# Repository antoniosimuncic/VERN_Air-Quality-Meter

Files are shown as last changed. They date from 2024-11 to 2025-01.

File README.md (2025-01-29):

# VERN' University  
Internet of Things Department  
Professor: doc. dr. sc. Petar Kolar, Roman Rubčić, dipl. ing. graf. teh.  
Student: Antonio Šimunčić  

**Smart air quality monitor**  

Zagreb, Croatia  
November, 2024  

# Introduction to the Smart Air Quality Monitor Project

Air pollution is becoming an increasingly serious environmental and health issue, affecting people's quality of life worldwide. Harmful particles and gases in the atmosphere can lead to numerous health problems, making air quality monitoring essential for protecting health and the environment.

The goal of this project is to develop a Smart Air Quality Monitor, a smart meteorological station that integrates advanced sensors to measure airborne dust particles, CO2, humidity, pressure, and temperature. This device would enable real-time air quality monitoring, providing users with critical information to help them make informed decisions and take necessary precautions.

# Week 1 - System architecture

Project Requirements:  

- **Temperature and Humidity Measurement**
- **Dust Particle Measurement** (PM1, PM2.5, PM4, PM10)
- **VOC Index Measurement** (Volatile Organic Compounds)
- **CO2 Level Measurement** in the Air
- **Atmospheric Pressure Measurement**
- **User Data Display**
- **Wireless Network Connectivity**

After defining the device requirements, I began searching for suitable components on platforms like Mouser, TME, and Aliexpress to find those that best match the specifications. The goal was to select reliable components that ensure high accuracy and longevity of the system, while also being compatible with the microcontroller and its software support.

For the microcontroller, I chose the ESP32-S3-WROOM-1 (N16R8) due to its affordable price, dual-core processor, ample onboard flash memory (16MB), and integrated PSRAM (8MB), which serves as a frame buffer for generating the graphical interface. Additionally, the microcontroller module includes built-in Wi-Fi and Bluetooth RF interfaces and an antenna, which significantly shortens development time and reduces the risk of wireless communication issues. 

**Block diagram:**  

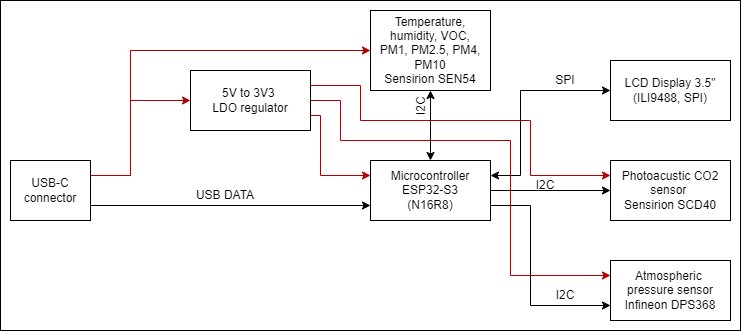
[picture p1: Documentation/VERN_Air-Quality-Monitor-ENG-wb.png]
Block diagram photo
  

# Week 2 - Schematic drawing

In week 2, I began creating the schematic in KiCad. The first task was to place all the selected components in the schematic, followed by a detailed study of the datasheets for the chosen components to ensure correct connections and desired system functionality. At this stage, I am also working on optimizing the schematic and the Bill of Materials (BOM) for a smooth transition to PCB design later on.

# Week 3 - Schematic release

In week 3, I completed the schematic design and released the finalized version. This involved thoroughly verifying all component connections and ensuring compatibility across the system, focusing on power distribution, signal integrity, and communication pathways between components. After careful checks, I created a preliminary Bill of Materials (BOM) and added detailed annotations to the schematic to guide the upcoming PCB layout phase. The release of the schematic marks a significant milestone, setting the foundation for the PCB design and allowing for initial testing.

**Schematic:** [Revision 10](https://github.com/antoniosimuncic/VERN_Air-Quality-Meter/blob/main/Hardware/100008_hw-vern-aqm/Schematic/100008_hw-vern-aqm.pdf)

# Week 4 - PCB design

In the fourth week of the project, I began designing the PCB based on the finalized schematic. This phase involved selecting the appropriate board dimensions, component placement, and routing the connections while considering design rules such as trace width, clearance, and power and heat management. A key focus was on USB differential pair impedance control, ensuring that the USB signal traces were routed with the correct 90Ω differential impedance to maintain signal integrity and reliable data transfer. I also worked on optimizing the layout for signal integrity, minimizing the length of high-speed signal traces, and ensuring proper reference planes and return paths for the components. After completing the layout and routing, I performed a Design Rule Check (DRC) to identify and correct any potential issues before moving on to generating the Gerber files for fabrication.

**PCB render:**  

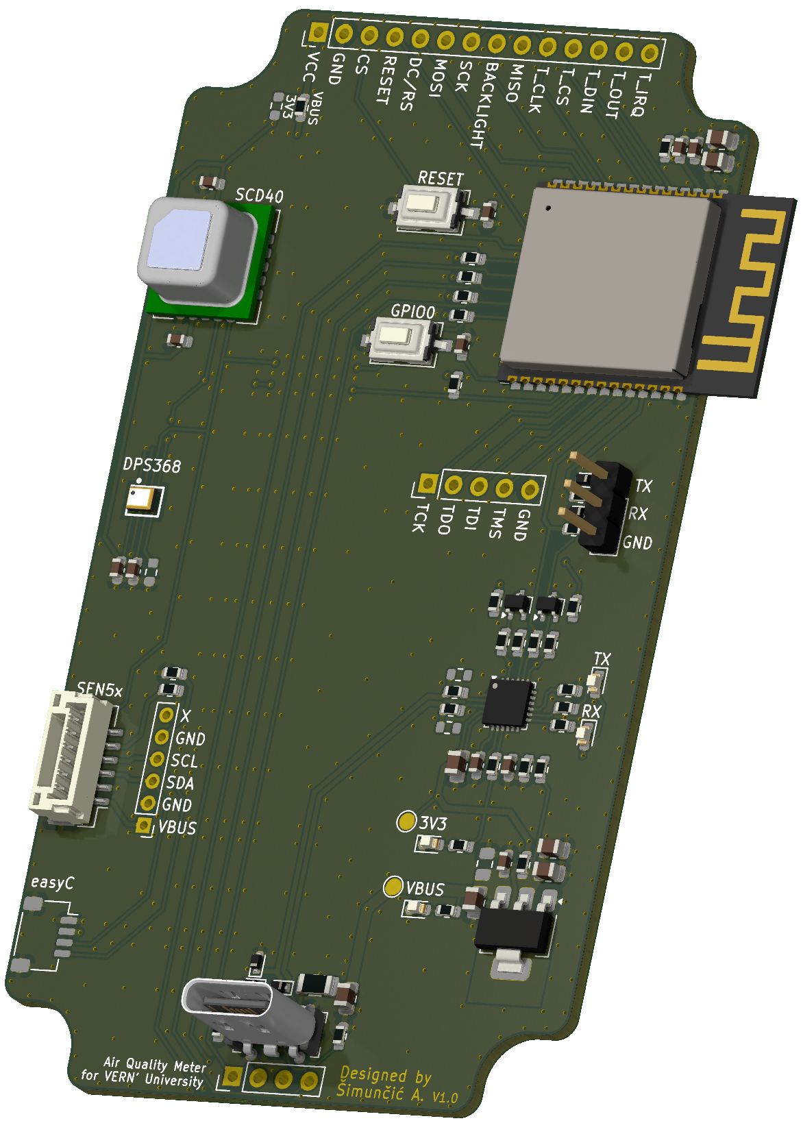
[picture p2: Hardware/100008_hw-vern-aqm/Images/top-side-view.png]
PCB render photo
  

# Week 5 - Component procurement  

In week 5, I focused on component procurement and ordering essential parts to prepare for assembly. I purchased components from Mouser to ensure the reliability of critical parts while sourcing additional items from Aliexpress for cost-effectiveness. Additionally, I ordered the PCBs and a stencil for solder application from JLCPCB. With components and PCBs on the way, the project is set to progress smoothly into the assembly phase once all parts arrive.

[Bill of Materials](https://html-preview.github.io/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)  

[Project expense report](https://github.com/antoniosimuncic/VERN_Air-Quality-Meter/blob/main/Documentation/project-expense-report.md)  

# Week 6 - PCB Assembly  

In week 6, I began assembling the PCB as the components and boards had arrived. Using the stencil from JLCPCB, I applied solder paste to the pads, and then I carefully placed each component onto the board, paying special attention to orientation and alignment. After assembling the board, I placed the board on an SMD hotplate reflow soldering station to perform the reflow soldering process. After the board cooled down, I inspected the connections to ensure the soldering process finished successfully. With the PCB assembly complete, I began the first board power-up to do the initial testing and troubleshooting.  

**Production process:**  

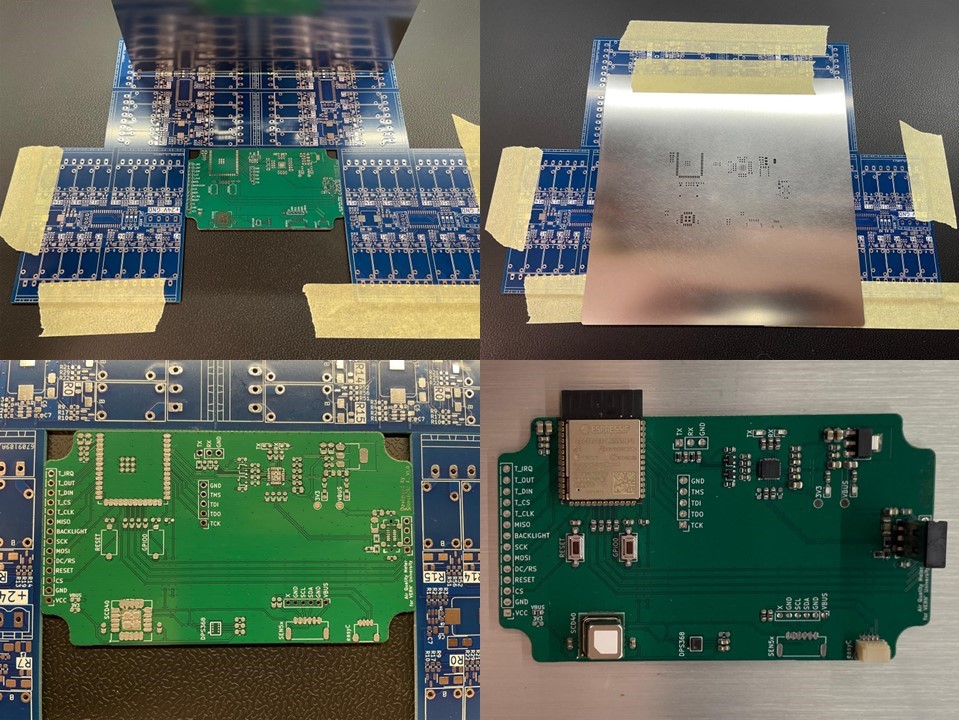
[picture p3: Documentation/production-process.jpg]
Photo of the production process
  

# Week 7 - Board Bring-Up  

In week 7, I focused on the initial bring-up of the PCB. After assembling the board, I verified the power rails and ensured all components received the correct voltages. Basic functionality, including communication interfaces such as UART and I2C, was tested to confirm proper connectivity between the microcontroller and peripherals. Rigol DS1054z oscilloscope was used to identify and resolve minor issues on the UART lines. Soldering fixes were necessary to ensure the board operated as expected. This stage established a solid foundation for further firmware development and system testing.  

**Sensor test source code:** [sensors-bring-up.cpp](https://github.com/antoniosimuncic/VERN_Air-Quality-Meter/blob/main/Documentation/sensors-bring-up.cpp)  

# Week 8 - Case design  

In week 8, I focused on designing a custom 3D-printed case for the device after I had confirmed the board functioned as expected. The design accounted for component placement, ventilation, and accessibility for ports and connectors. Aesthetics and durability were considered to ensure the case complemented the functionality and appearance of the project. This step helped prepare the device for practical use and testing in real-world conditions. The 3D print was made using PET-G on the BambuLab P1S printer.  

**Case design:**  

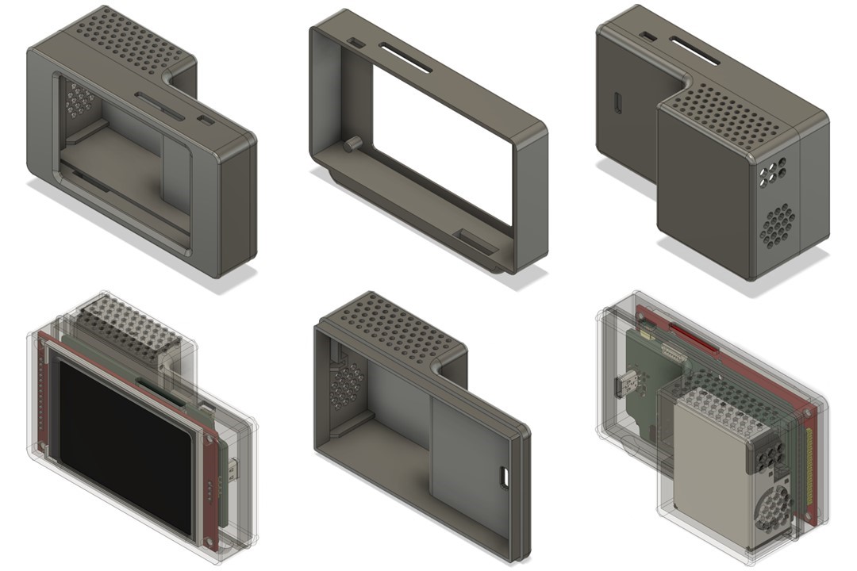
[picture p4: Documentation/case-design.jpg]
Photo of the case design
  

# Week 9: Firmware Architecture and Server Communication

In week 9, the focus was on developing and refining the firmware responsible for Wi-Fi connectivity, data acquisition, and communication with an HTTP server. Below is a detailed breakdown of the tasks completed and code implementations.

### Wi-Fi Connectivity

The firmware establishes a Wi-Fi connection using the ESP32-S3 microcontroller. A robust retry mechanism was implemented to handle connection failures.

**Code Snippet**:
```c
void connectToWifi() {
    uint8_t attempt = 0;
    while (attempt < WIFI_RETRIES) {
        Serial.printf("Attempt %u to connect to Wi-Fi...\n", attempt++);
        WiFi.mode(WIFI_STA);
        WiFi.begin(SECRET_SSID, SECRET_PASSWORD);
        unsigned long startAttemptTime = millis();
        while (WiFi.status() != WL_CONNECTED && millis() - startAttemptTime < WIFI_TIMEOUT) {
            delay(10);
            yield();
        }
        if (WiFi.status() == WL_CONNECTED) {
            Serial.println("Connected to Wi-Fi");
            Serial.print("IP Address: ");
            Serial.println(WiFi.localIP());
            return;
        }
        Serial.println("Failed to connect. Retrying...");
        delay(2000);
        attempt++;
    }
    Serial.println("Exceeded maximum retry attempts. Check your Wi-Fi credentials or network.");
}
```

### Server Communication

Data collected from sensors is sent to an HTTP server in JSON format. The sendDataToHTTPServer function handles this process, including constructing the JSON payload and managing HTTP requests.

**Request body:**
```json
{
 "mac_address": "AA:BB:CC:DD:EE:FF",
 "temperature": 22.5,
 "humidity": 45.0,
 "pm1": 10,
 "pm2_5": 20,
 "pm4": 25,
 "pm10": 30,
 "co2": 450,
 "voc": 100,
 "pressure": 1013.25
}
```
     
**Code Snippet:**
```c
void sendDataToHTTPServer(String mac_address, float temperature, float humidity, float pm1, float pm2_5, float pm4, float pm10, uint16_t co2, float voc, float pressure) {
    String jsonData = "{";
    jsonData += "\"mac_address\":\"" + mac_address + "\",";
    jsonData += "\"temperature\":" + String(temperature) + ",";
    jsonData += "\"humidity\":" + String(humidity) + ",";
    jsonData += "\"pm1\":" + String(pm1) + ",";
    jsonData += "\"pm2_5\":" + String(pm2_5) + ",";
    jsonData += "\"pm4\":" + String(pm4) + ",";
    jsonData += "\"pm10\":" + String(pm10) + ",";
    jsonData += "\"co2\":" + String(co2) + ",";
    jsonData += "\"voc\":" + String(voc) + ",";
    jsonData += "\"pressure\":" + String(pressure);
    jsonData += "}";

    if (WiFi.status() == WL_CONNECTED) {
        HTTPClient http;
        http.begin(SERVER_URL);
        http.addHeader("Content-Type", "application/json");
        int httpResponseCode = http.POST(jsonData);
        if (httpResponseCode > 0) {
            String response = http.getString();
            Serial.println("Response code: " + String(httpResponseCode));
            Serial.println("Response: " + response);
        } else {
            Serial.println("Error on sending POST: " + String(httpResponseCode));
        }
        http.end();
    } else {
        Serial.println("Wi-Fi not connected");
    }
}
```
**View Full Code:** [server_functions.cpp](https://github.com/antoniosimuncic/VERN_Air-Quality-Meter/blob/main/Software/100009-fw-vern-aqm/lib/server_functions/server_functions.cpp)

# Week 10: LCD Integration and Sensor Visualization

In week 10, the focus shifted to integrating the TFT display for visualizing sensor data. The firmware includes functionality for determining display colors based on sensor values, enhancing user experience.

### Dynamic Value Coloring

Each sensor value is displayed in a color-coded format to indicate its status (e.g., good, mediocre, bad, terrible).  
Functions like `getTempColor()` and `getHumidityColor()` determine the appropriate color for each value.

**Code Snippet:**
```c
uint16_t getHumidityColor(float humidity) {

    uint8_t targetHumidity = 50;
    if (abs(targetHumidity-humidity) <= 10) {
        return GOOD_COLOR;  // Green for humidity 40-60%
    } else if (abs(targetHumidity-humidity) <= 15) {
        return MEDIOCRE_COLOR;  // Yellow for humidity 35-65%
    } else if (abs(targetHumidity-humidity) <= 20) {
        return BAD_COLOR;  // Orange for humidity 30-70%
    } else {
        return TERRIBLE_COLOR;  // Red for humidity under 30 or over 70%
    }
}
```
**View Full Code:** [lcd_functions.cpp](https://github.com/antoniosimuncic/VERN_Air-Quality-Meter/blob/main/Software/100009-fw-vern-aqm/lib/lcd_functions/lcd_functions.cpp)

### Sensor Value Visualization

The display shows sensor values for temperature, humidity, CO2, VOC Index, and particulate matter (PM1, PM2.5, PM10). Each value is updated dynamically and rendered in real time.

**Code Snippet:**
```c
// Draw initial UI with Wi-Fi credentials
void drawUI() {
    sprite.fillSprite(BACKGROUND_COLOR);

    drawClockAndWiFi();

    sprite.setTextDatum(TL_DATUM); // Top-left
    sprite.setTextColor(TEXT_COLOR, TOP_BAR_COLOR);
    sprite.setTextSize(3);
    sprite.drawString("Time Zone", 10, 8);
    sprite.setTextDatum(TL_DATUM); // Top-left
    sprite.setTextColor(TEXT_COLOR, BACKGROUND_COLOR);
    sprite.setTextSize(3);
    sprite.drawString("SSID:", 20, 60);  sprite.drawString(SECRET_SSID, 120, 60);
    sprite.drawString("PASS:", 20, 120); sprite.drawString(SECRET_PASSWORD, 120, 120);
    sprite.drawString("IP:", 20, 180); sprite.drawString(ipString, 120, 180);

    sprite.pushSprite(0, 0);
    sprite.fillRect(0,35,480,285, BACKGROUND_COLOR);
    sprite.pushSprite(0, 0);

}

// Draw widgets with specified values
void drawWidget(int x, int y, int w, int h, const char* label, const char* unit, const char* value, uint16_t color) {
    // Draw the rounded rectangle
    sprite.fillRoundRect(x, y, w, h, 10, color);
    sprite.fillRoundRect(x + 5, y + 5, w - 10, h - 10, 5, BACKGROUND_COLOR);

    // Draw the label
    sprite.setTextColor(TEXT_COLOR, BACKGROUND_COLOR);
    sprite.setTextDatum(TC_DATUM);
    sprite.setTextSize(2);
    sprite.drawString(label, x + w / 2, y + 12);

    // Draw the value
    sprite.setTextSize(2);
    sprite.setTextColor(MEASUREMENT_TEXT_COLOR, BACKGROUND_COLOR);
    sprite.drawString(value, x + w / 2, (y + h / 2)-10);

    // Draw the measurement unit
    sprite.setTextColor(TEXT_COLOR, BACKGROUND_COLOR);
    sprite.setTextDatum(TC_DATUM);
    sprite.setTextSize(2);
    sprite.drawString(unit, x + w / 2, y + 80);
}

// Update each widget with new sensor values
void updateUI() {
    uint8_t x = 3;
    uint8_t y = 55;
    uint8_t w = 110;
    uint8_t h = 110;
    uint8_t v_space = 25;

    drawWidget(x +   0, y, w, h, "Temp",     "C",   String(TEMPERATURE, 1).c_str(),  getTempColor(TEMPERATURE));
    drawWidget(x + 120, y, w, h, "RH",       "%",   String(HUMIDITY, 1).c_str(),     getHumidityColor(HUMIDITY));
    drawWidget(x + 240, y, w, h, "CO2",      "ppm", String(CO2).c_str(),             getCO2Color(CO2));
    drawWidget(x + 360, y, w, h, "Pressure", "hPa", String(PRESSURE/100, 2).c_str(), getPressureColor(PRESSURE));

    drawWidget(x +   0, y + h + v_space, w, h, "VOC",   "Index", String(VOC_INDEX, 0).c_str(), getVOCColor(VOC_INDEX));
    drawWidget(x + 120, y + h + v_space, w, h, "PM1",   "ug/m3", String(PM1, 0).c_str(),       getPM1Color(PM1));
    drawWidget(x + 240, y + h + v_space, w, h, "PM2.5", "ug/m3", String(PM2_5, 0).c_str(),     getPM2_5Color(PM2_5));
    drawWidget(x + 360, y + h + v_space, w, h, "PM10",  "ug/m3", String(PM10, 0).c_str(),      getPM10Color(PM10));

    drawClockAndWiFi();

    sprite.pushSprite(0, 0);
}
```
### Time and Wi-Fi indicator  

The top bar of the display is reserved for a digital clock that syncs with a NTP time server on the Wi-Fi network, there is also a red/green dot in the upper right corner that shows Wi-Fi status.

```c
// Draw clock and Wi-Fi indicator
void drawClockAndWiFi() {
    // Draw clock
    unsigned long currentEpoch = timeClient.getEpochTime();
    String currentTime = epochToHoursMinutes(currentEpoch);

    sprite.fillRect(0,0,480,35, TOP_BAR_COLOR);
    sprite.setTextDatum(TC_DATUM); // Top-center
    sprite.setTextColor(TEXT_COLOR, TOP_BAR_COLOR);
    sprite.setTextSize(3);
    sprite.drawString(currentTime, 240, 8);

    // Draw WiFi symbol and indication
    if (WiFi.status() == WL_CONNECTED) {
        sprite.fillCircle(455, 18, 7, TFT_GREEN); // Indicate WiFi connection (green dot)
    } else {
        sprite.fillCircle(455, 18, 7, TFT_RED); // Indicate NO WiFi connection (red dot)
    }
}
```
**View Full Code:** [main.cpp](https://github.com/antoniosimuncic/VERN_Air-Quality-Meter/blob/main/Software/100009-fw-vern-aqm/src/main.cpp)

# Week 11 and 12: Node.js Server with visual data dashboard

Last part of the project was to design a web-application for managing the sensors and viewing and storing the data.  

**Web-App Repository**: [Nodejs-IoT-Server](https://github.com/antoniosimuncic/nodejs-iot-server)  

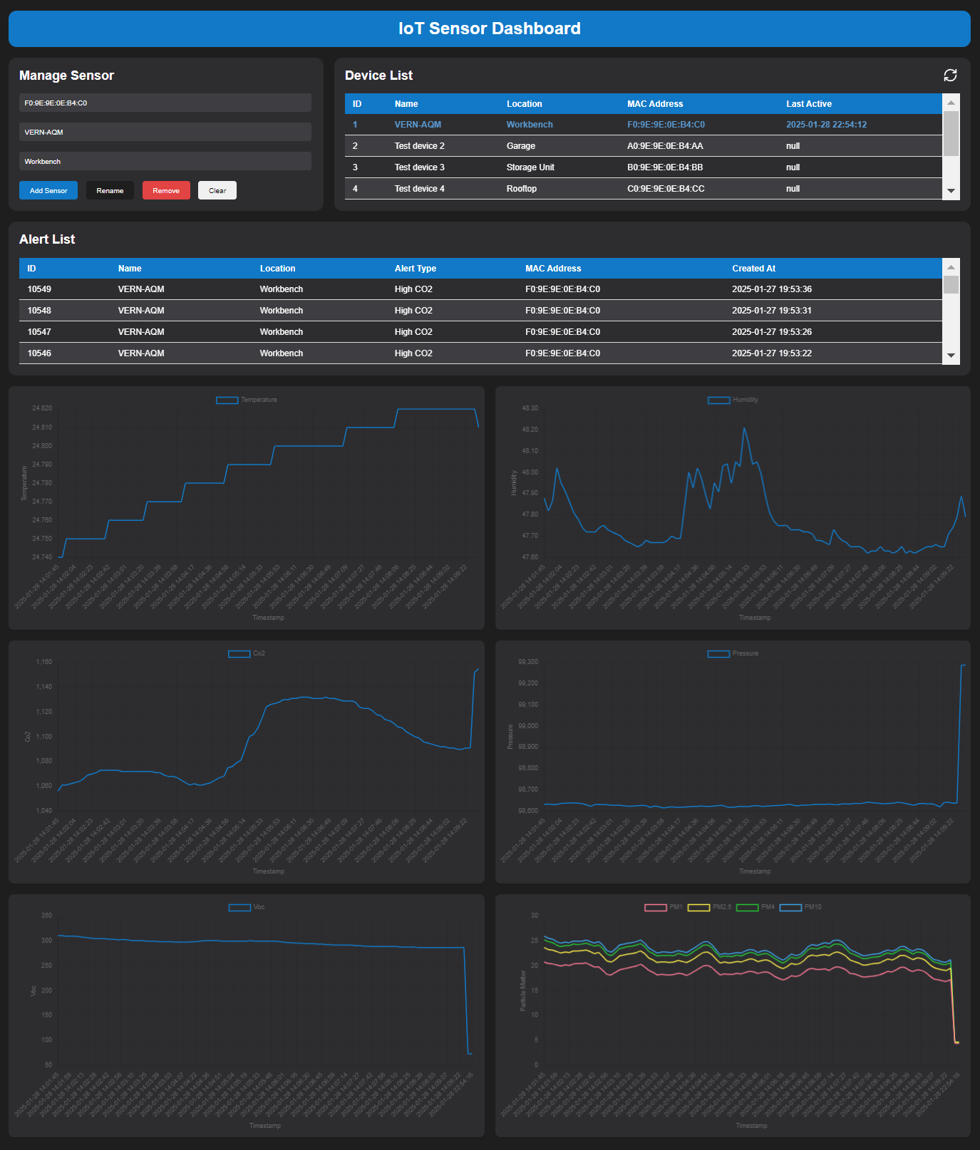
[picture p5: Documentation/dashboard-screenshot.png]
IoT Sensor Dashboard
  

---

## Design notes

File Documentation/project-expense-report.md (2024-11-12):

# Expense report:  
AliExpress: - 19.27€
- 2x 3.5" TFT LCD ILI9488 - 9.64€

JLCPCB: - 52.73€
- 5x 4-Layer PCB - 6.52€
- 1x SMD stencil - 6.62€
- Shipping - 29.04€
- Import duties and VAT - 10.55€

Mouser: - 77.11€
- Components - 61.69€
- VAT - 15.42€

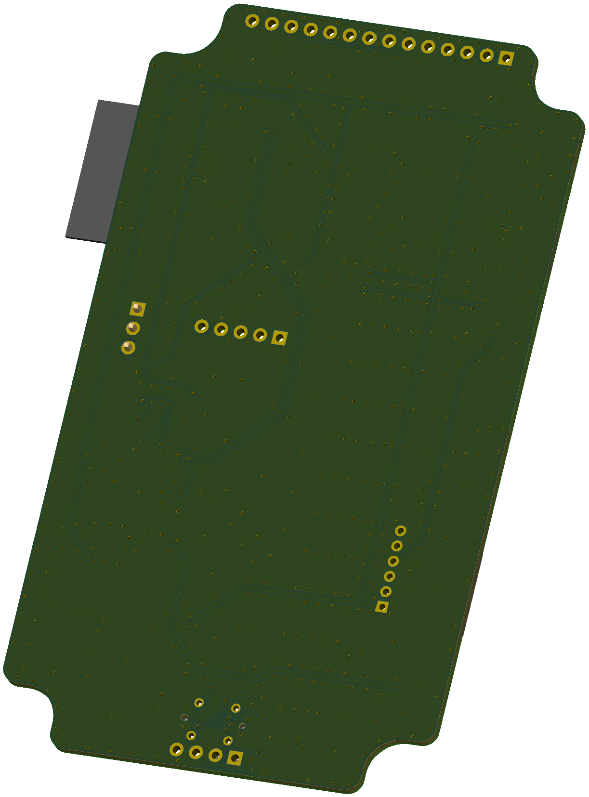
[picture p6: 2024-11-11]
Hardware/100008_hw-vern-aqm/Images/bottom-side-view.png

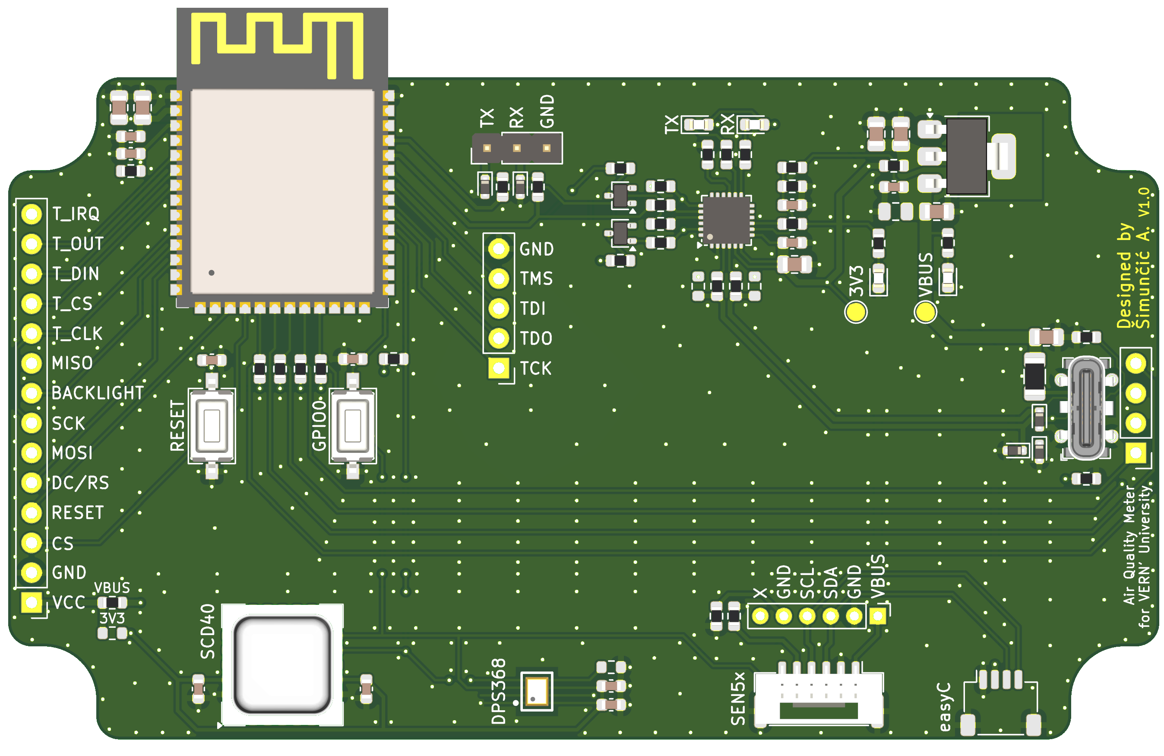
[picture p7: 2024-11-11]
Hardware/100008_hw-vern-aqm/Images/top-view.png

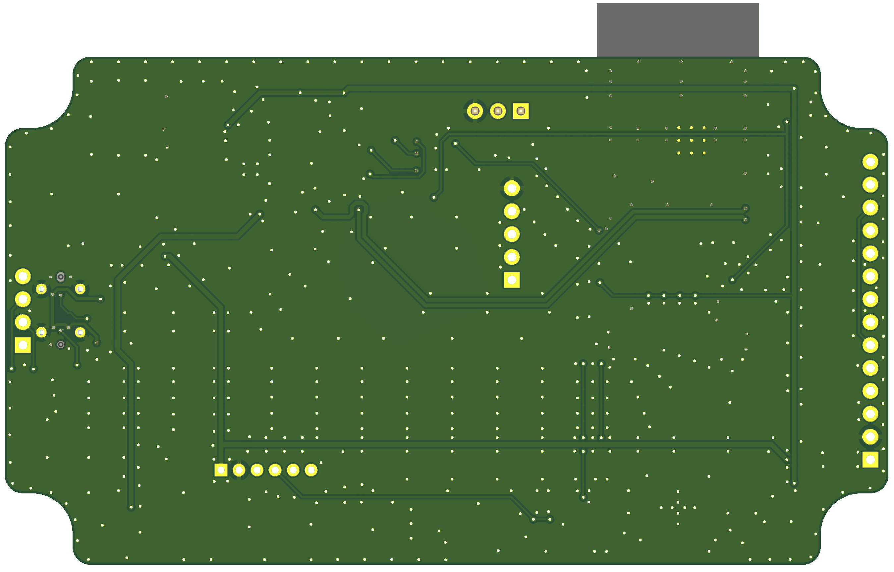
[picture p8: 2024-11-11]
Hardware/100008_hw-vern-aqm/Images/bottom-view.bmp

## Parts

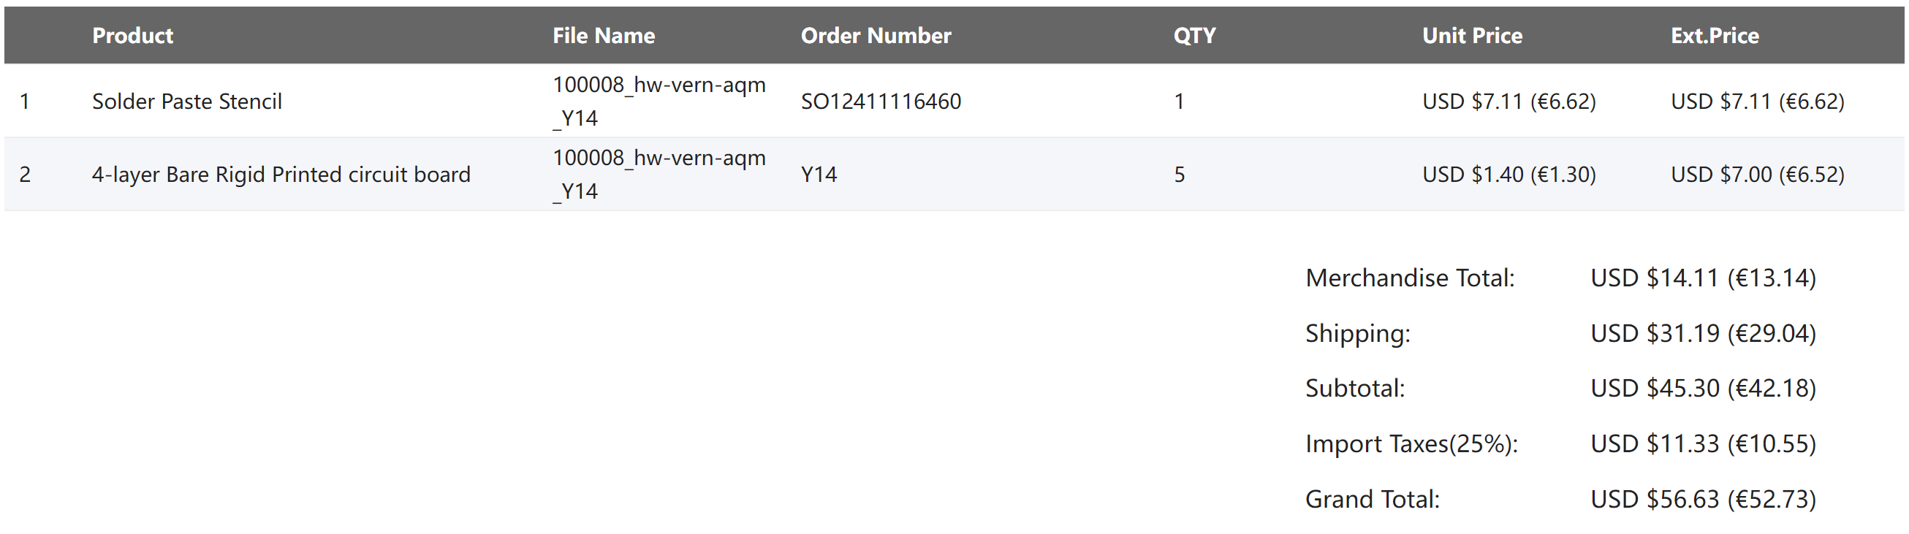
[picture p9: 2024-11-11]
Hardware/100008_hw-vern-aqm/Manufacturing/Procurement/jlcpcb-order.png

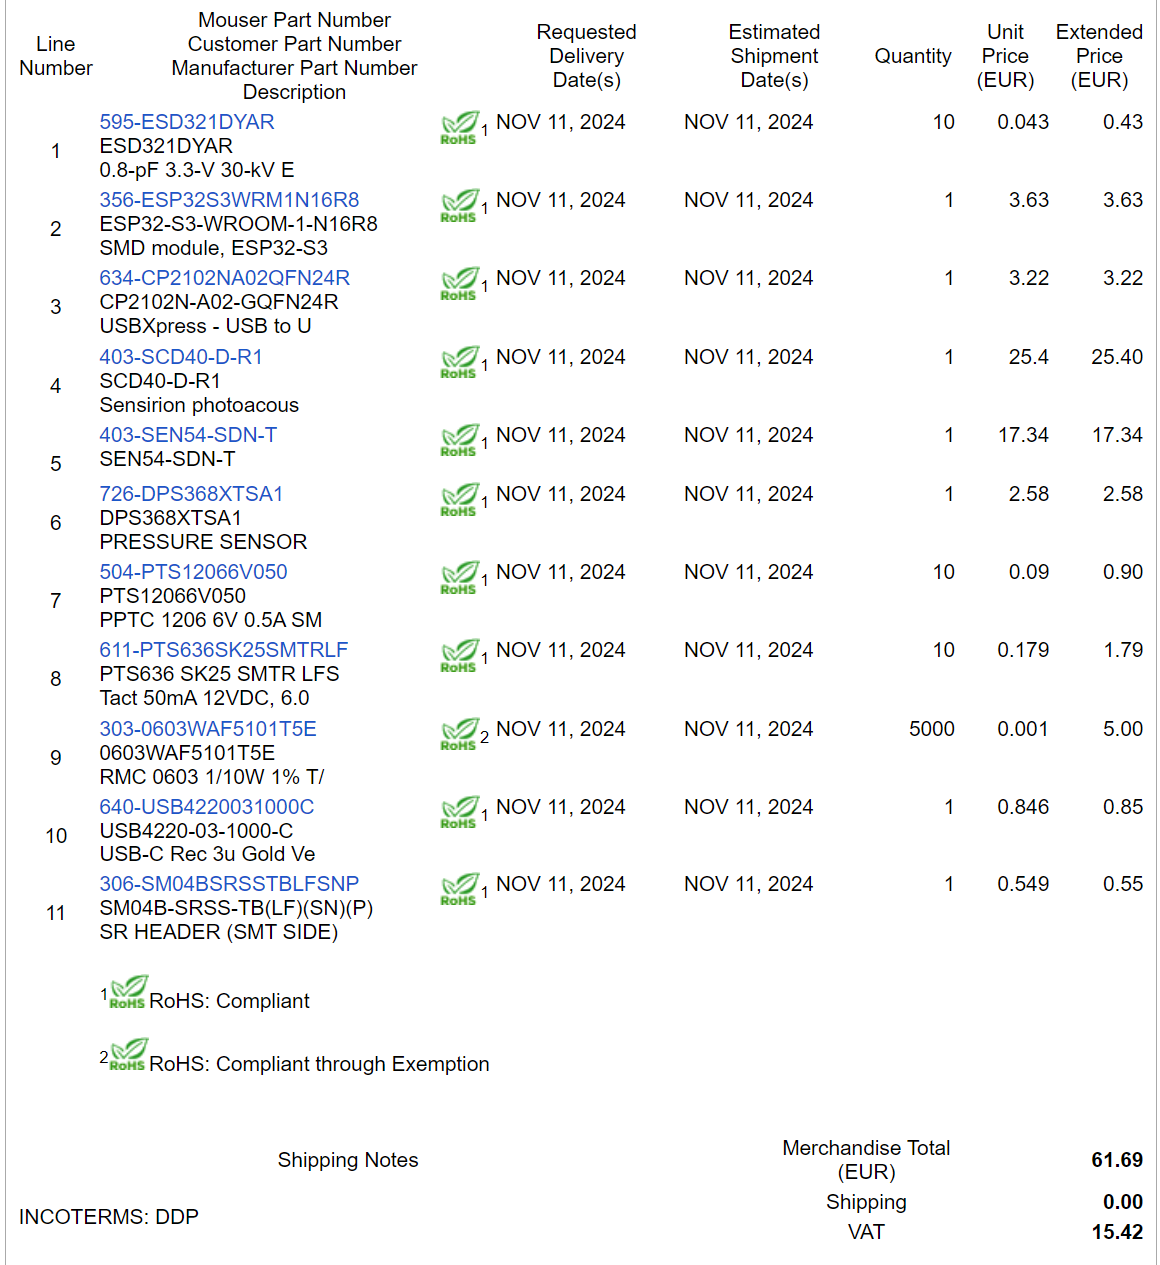
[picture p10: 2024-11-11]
Hardware/100008_hw-vern-aqm/Manufacturing/Procurement/mouser-order.png

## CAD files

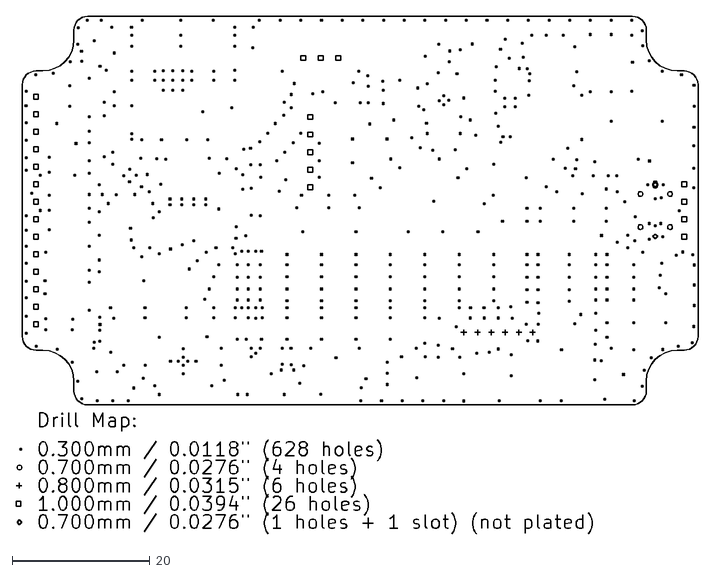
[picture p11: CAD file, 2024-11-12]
Hardware/100008_hw-vern-aqm/Manufacturing/Fabrication/Gerbers/100008_hw-vern-aqm-drl_map.dxf
98.9 x 75.0

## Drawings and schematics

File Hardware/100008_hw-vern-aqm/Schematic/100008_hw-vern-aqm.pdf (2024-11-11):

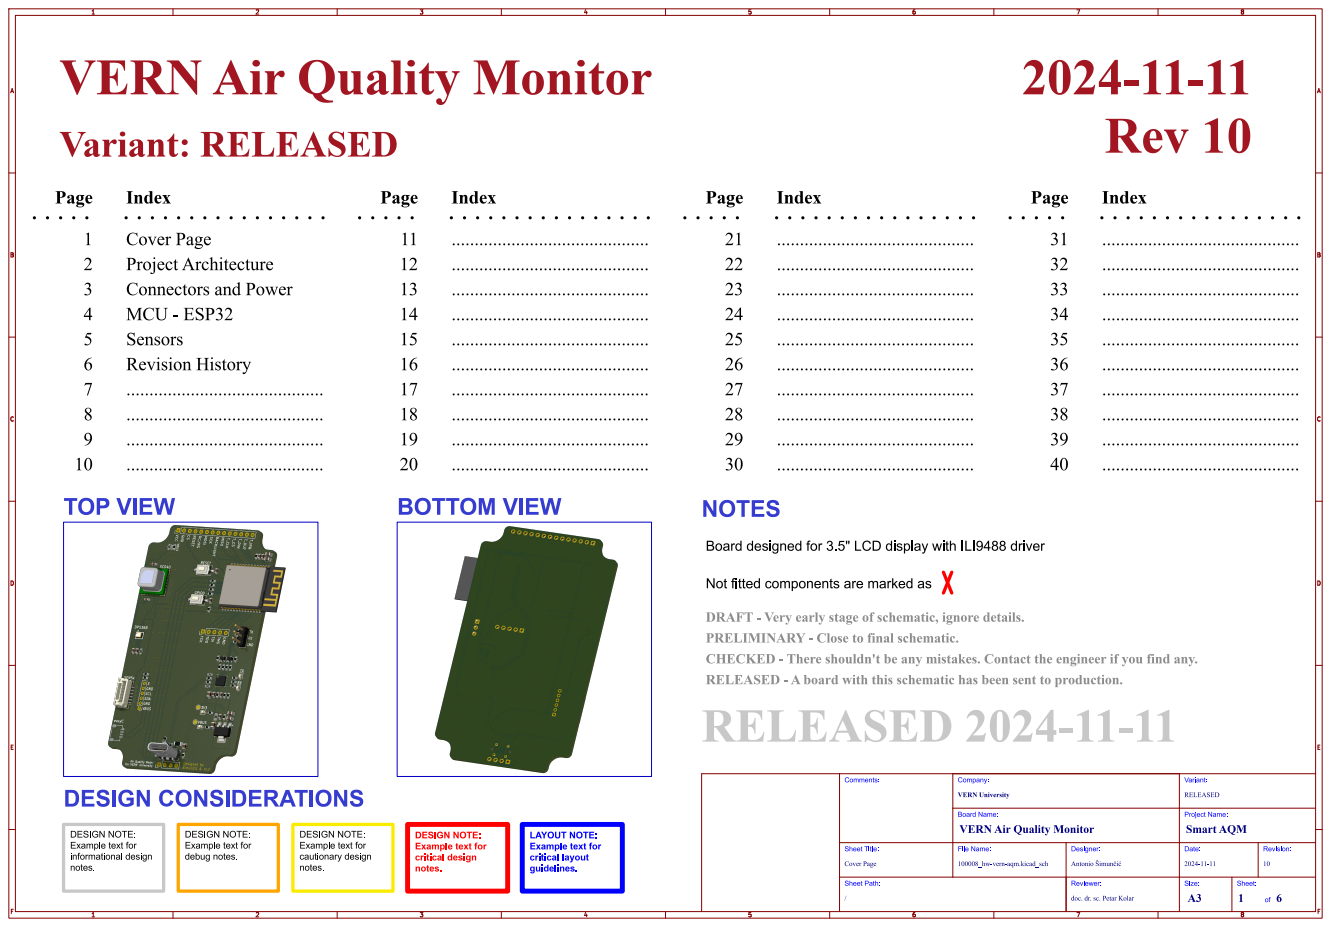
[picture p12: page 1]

Board designed for 3.5" LCD display with ILI9488 driver ...........................................

Not fitted components are marked as

DRAFT - Veryearlystageof schematic,ignoredetails.
PRELIMINARY - Closetofinal schematic.
CHECKED - Thereshouldn'tbeanymistakes.Contacttheengineerif youfindany.
RELEASED 2024-11-11

Revision: 10 Date: Project Name: 2024-11-11 Reviewer: doc.dr.sc.PetarKolar Designer:

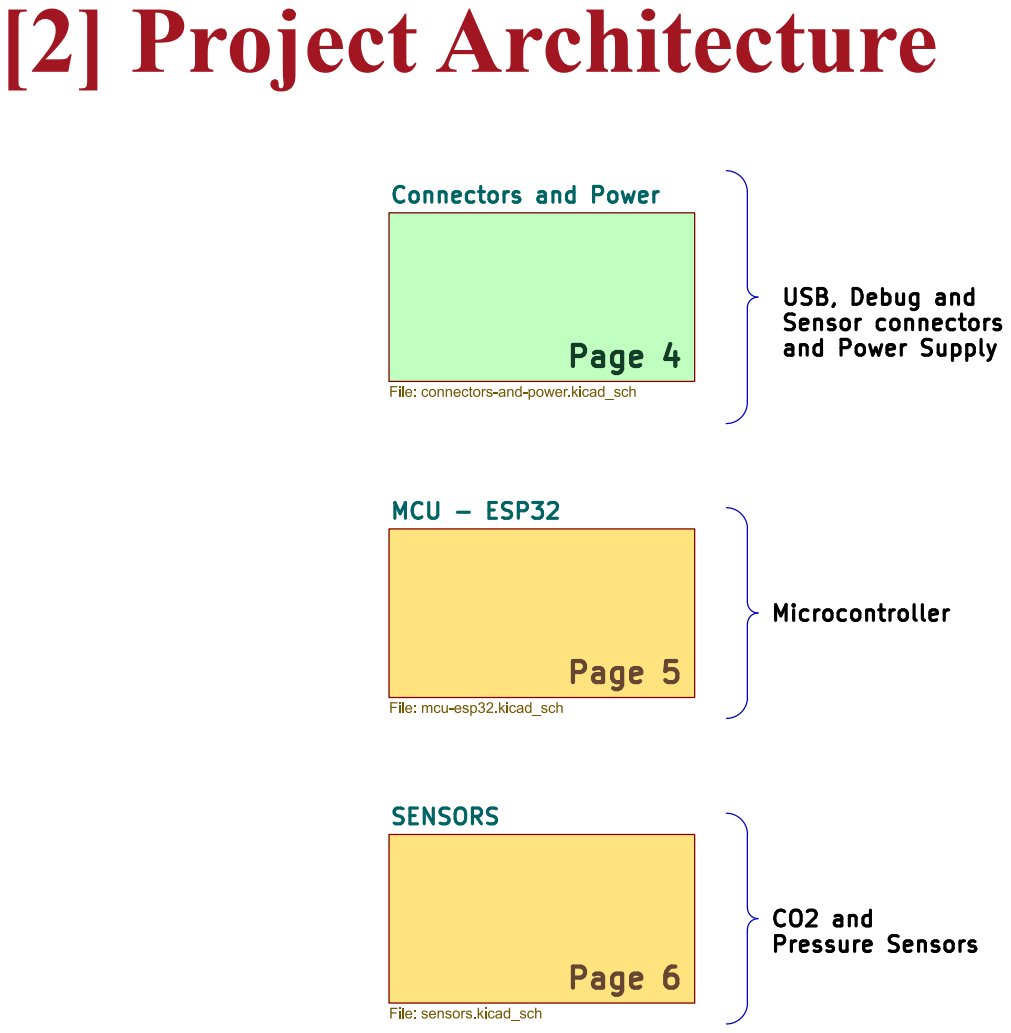
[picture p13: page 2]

/ProjectArchitecture/ Sheet Path: ProjectArchitecture Comments:

Revision: 10 Date: Project Name: LastModified Date Reviewer: doc.dr.sc.PetarKolar Designer:

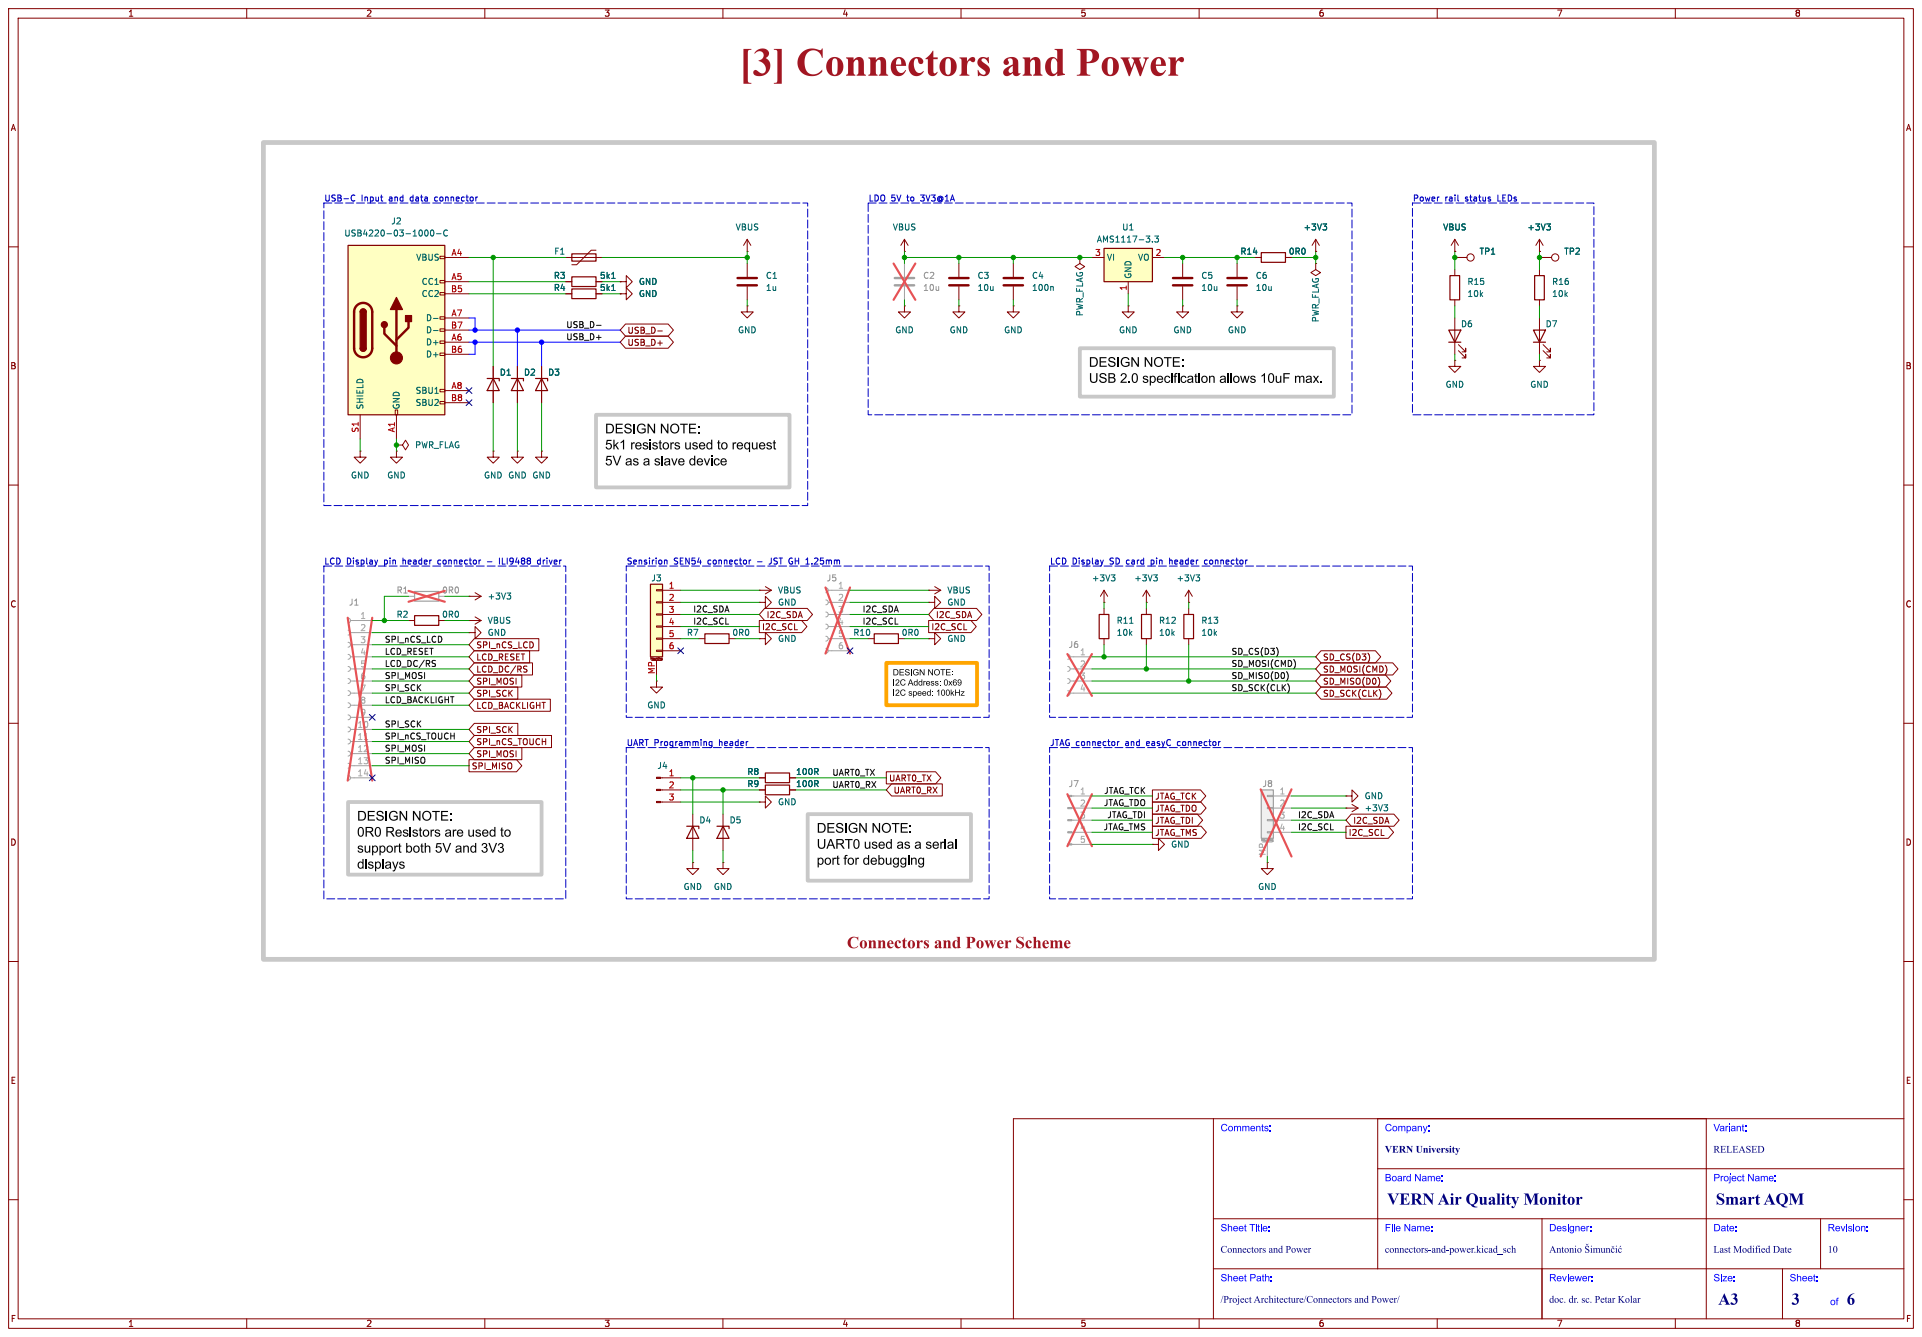
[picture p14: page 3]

USB 2.0 specification allows 10uF max. DESIGN NOTE:

5k1 resistors used to request
5V as a slave device
I2C_SDA UART0_RX

DESIGN NOTE:
0R0 Resistors are used to
support both 5V and 3V3
displays

/ProjectArchitecture/ConnectorsandPower/ Sheet Path: ConnectorsandPower Comments:

Revision: 10 Date: Project Name: LastModified Date Reviewer: doc.dr.sc.PetarKolar Designer:

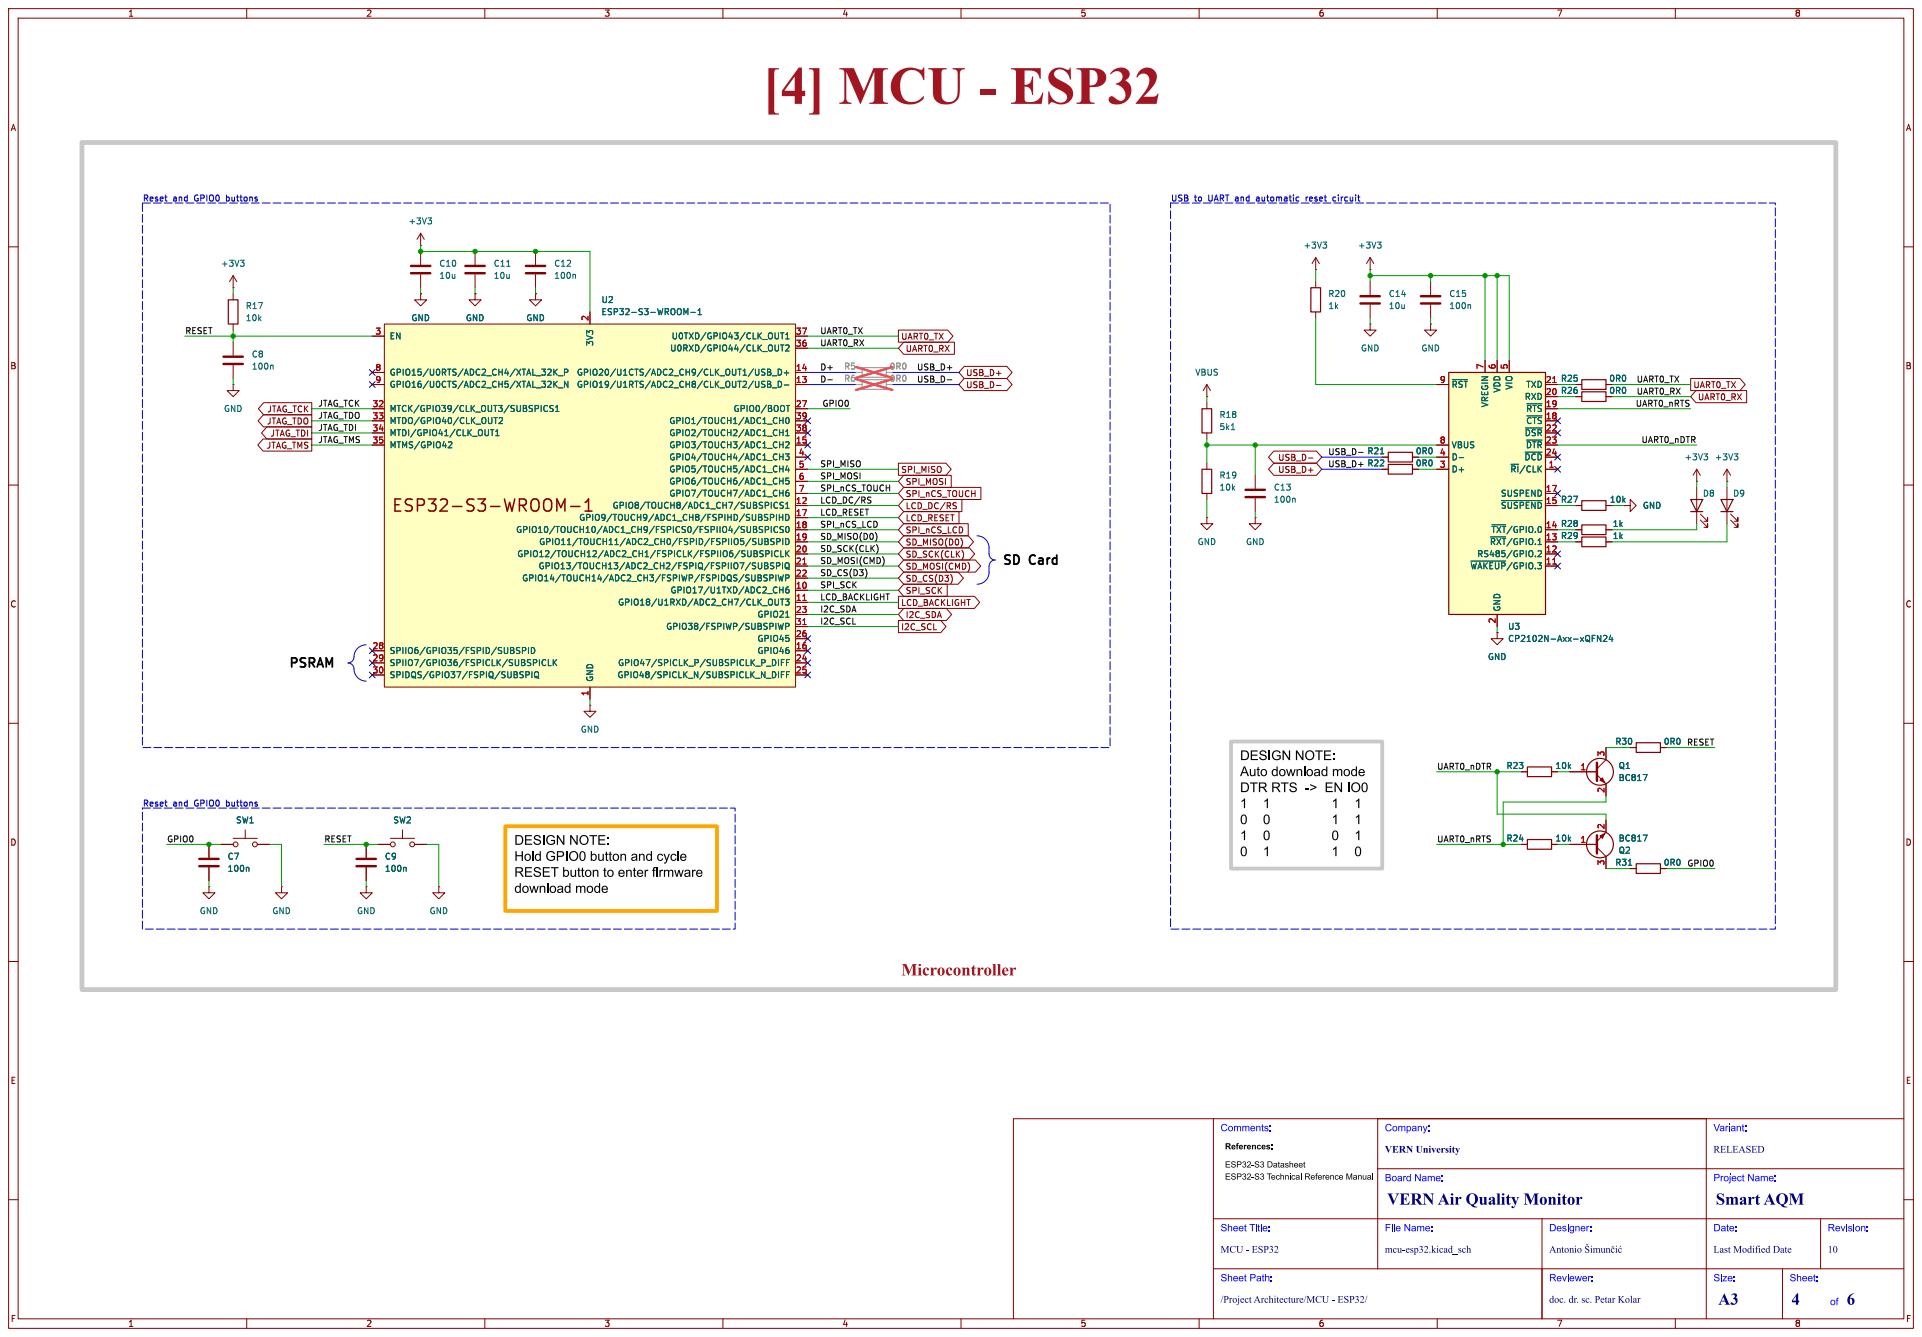
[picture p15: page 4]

2 GPIO12/TOUCH12/ADC2_CH1/FSPICLK/FSPIIO6/SUBSPICLK 20 GPIO13/TOUCH13/ADC2_CH2/FSPIQ/FSPIIO7/SUBSPIQ 21 GPIO14/TOUCH14/ADC2_CH3/FSPIWP/FSPIDQS/SUBSPIWP 22 GPIO21 23 GPIO47/SPICLK_P/SUBSPICLK_P_DIFF 24 GPIO48/SPICLK_N/SUBSPICLK_N_DIFF 25 GPIO45 26 GPIO0/BOOT 27 SPIIO6/GPIO35/FSPID/SUBSPID 28 SPIIO7/GPIO36/FSPICLK/SUBSPICLK 29 EN 3 SPIDQS/GPIO37/FSPIQ/SUBSPIQ 30 GPIO38/FSPIWP/SUBSPIWP 31 MTCK/GPIO39/CLK_OUT3/SUBSPICS1 32 MTDO/GPIO40/CLK_OUT2 33 MTDI/GPIO41/CLK_OUT1 34 MTMS/GPIO42 35 U0RXD/GPIO44/CLK_OUT2 36 U0TXD/GPIO43/CLK_OUT1 37 GPIO2/TOUCH2/ADC1_CH1 38 GPIO1/TOUCH1/ADC1_CH0 39 GPIO4/TOUCH4/ADC1_CH3 4 GPIO5/TOUCH5/ADC1_CH4 5 GPIO6/TOUCH6/ADC1_CH5 6 GPIO7/TOUCH7/ADC1_CH6 7 GPIO15/U0RTS/ADC2_CH4/XTAL_32K_P 8 GPIO16/U0CTS/ADC2_CH5/XTAL_32K_N 9 U2ESP32-S3-WROOM-1 R25 0R0 GND

2 GPIO12/TOUCH12/ADC2_CH1/FSPICLK/FSPIIO6/SUBSPICLK 20 GPIO13/TOUCH13/ADC2_CH2/FSPIQ/FSPIIO7/SUBSPIQ 21 GPIO14/TOUCH14/ADC2_CH3/FSPIWP/FSPIDQS/SUBSPIWP 22 GPIO21 23 GPIO47/SPICLK_P/SUBSPICLK_P_DIFF 24 GPIO48/SPICLK_N/SUBSPICLK_N_DIFF 25 GPIO45 26 GPIO0/BOOT 27 SPIIO6/GPIO35/FSPID/SUBSPID 28 SPIIO7/GPIO36/FSPICLK/SUBSPICLK 29 EN 3 SPIDQS/GPIO37/FSPIQ/SUBSPIQ 30 GPIO38/FSPIWP/SUBSPIWP 31 MTCK/GPIO39/CLK_OUT3/SUBSPICS1 32 MTDO/GPIO40/CLK_OUT2 33 MTDI/GPIO41/CLK_OUT1 34 MTMS/GPIO42 35 U0RXD/GPIO44/CLK_OUT2 36 U0TXD/GPIO43/CLK_OUT1 37 GPIO2/TOUCH2/ADC1_CH1 38 GPIO1/TOUCH1/ADC1_CH0 39 GPIO4/TOUCH4/ADC1_CH3 4 GPIO5/TOUCH5/ADC1_CH4 5 GPIO6/TOUCH6/ADC1_CH5 6 GPIO7/TOUCH7/ADC1_CH6 7 GPIO15/U0RTS/ADC2_CH4/XTAL_32K_P 8 GPIO16/U0CTS/ADC2_CH5/XTAL_32K_N 9 R6 0R0 R5 0R0 R26 0R0Q1 BC817

1 GPIO17/U1TXD/ADC2_CH6 10 GPIO18/U1RXD/ADC2_CH7/CLK_OUT3 11 GPIO8/TOUCH8/ADC1_CH7/SUBSPICS1 12 GPIO19/U1RTS/ADC2_CH8/CLK_OUT2/USB_D- 13 GPIO20/U1CTS/ADC2_CH9/CLK_OUT1/USB_D+ 14 GPIO3/TOUCH3/ADC1_CH2 15 GPIO46 16 GPIO9/TOUCH9/ADC1_CH8/FSPIHD/SUBSPIHD 17 GPIO10/TOUCH10/ADC1_CH9/FSPICS0/FSPIIO4/SUBSPICS0 18 GPIO11/TOUCH11/ADC2_CH0/FSPID/FSPIIO5/SUBSPID 19 3V3

2 RXD 20 TXD 21 ~{DSR} 22 ~{DTR} 23 ~{DCD} 24 D+ 3 D- 4 VIO

DESIGN NOTE:
Hold GPIO0 button and cycle
RESET button to enter firmware
download mode

/ProjectArchitecture/MCU- ESP32/ Sheet Path: MCU - ESP32 Comments: GND

Revision: 10 Date: Project Name: LastModified Date Reviewer: doc.dr.sc.PetarKolar Designer:

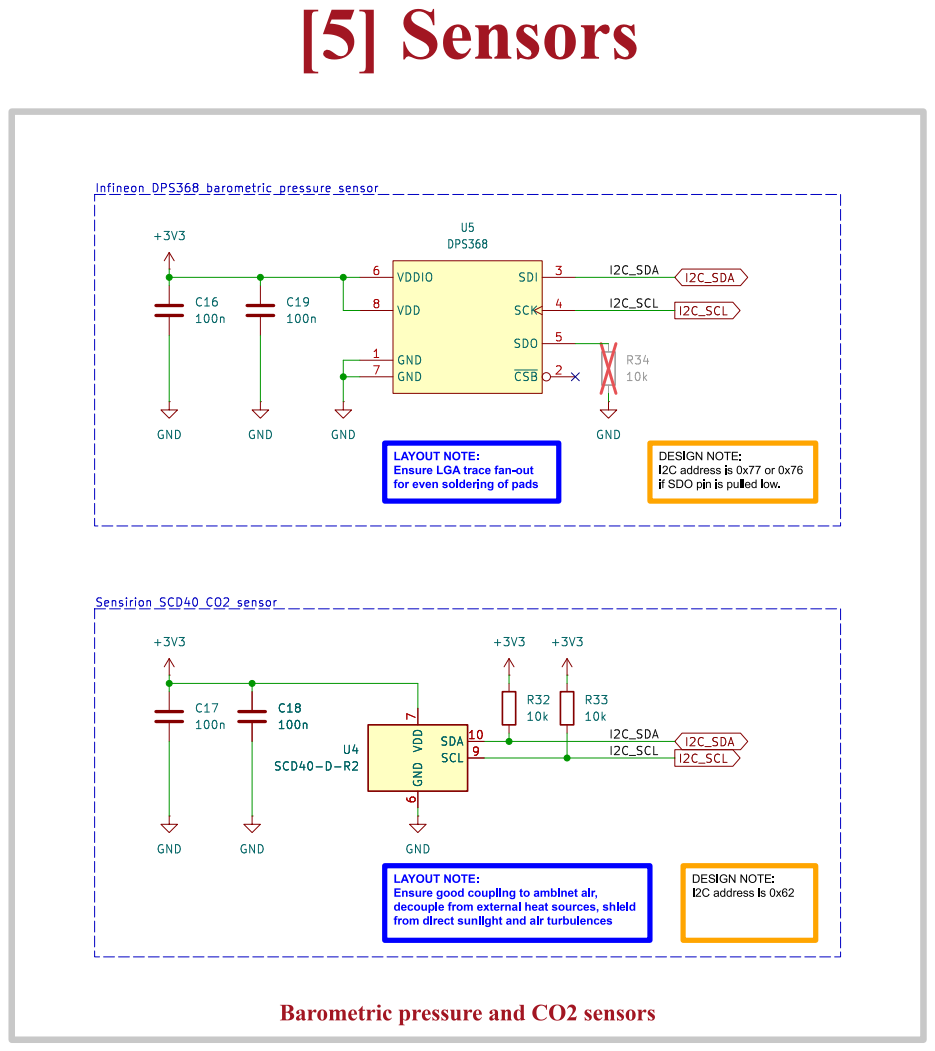
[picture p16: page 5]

from direct sunlight and air turbulences [5] Sensors
I2C_SCL

I2C_SDA
if SDO pin is pulled low. DESIGN NOTE:

LAYOUT NOTE: Ensure LGA trace fan-out

LAYOUT NOTE: Ensure good coupling to ambinet air, decouple from external heat sources, shield

/ProjectArchitecture/SENSORS/ Sheet Path: Sensors Comments:

Design-in Guide SCD4x CO2 Sensor (https://sensirion.com/media/documents/0D0C9129/623B1183/Sensirion_CO2_Sensors_SCD4x_design-in_guide.pdf)
Flexible I/O source configuration (https://jpieper.com/2022/06/28/flexible-i-o-source-configuration/)

Revision: 10 Date: Project Name: LastModified Date Reviewer: doc.dr.sc.PetarKolar Designer:

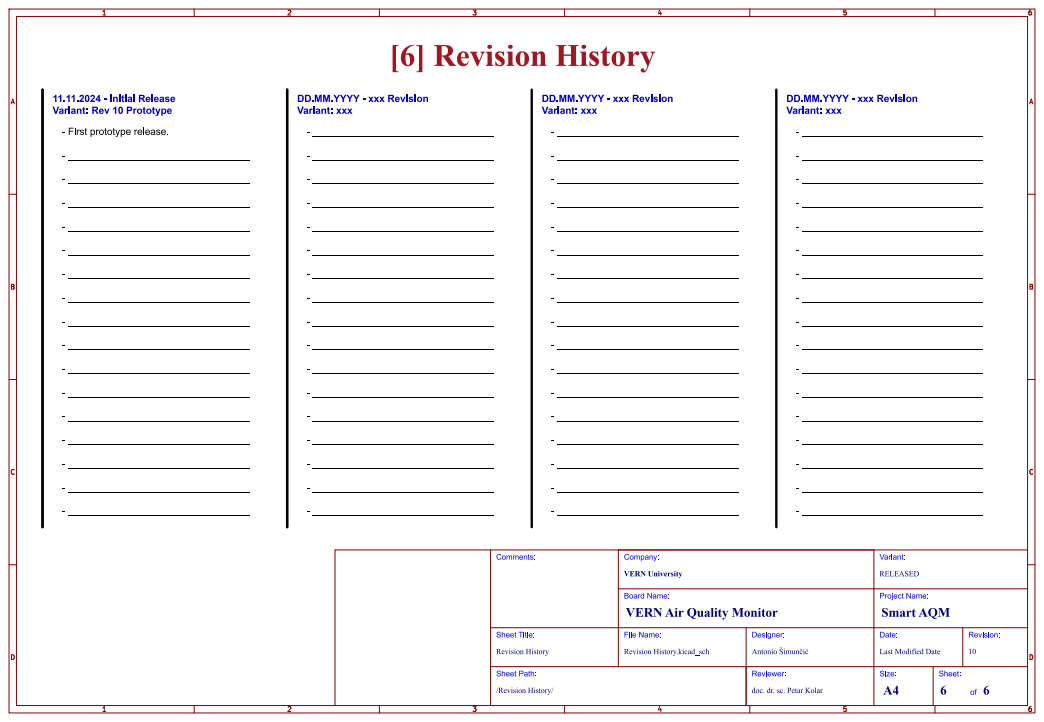
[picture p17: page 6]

/RevisionHistory/ Sheet Path: RevisionHistory Comments: DD.MM.YYYY - xxx Revision
Variant: xxx

- _________________________________ [6] RevisionHistory
- _________________________________ DD.MM.YYYY - xxx Revision

Variant: xxx DD.MM.YYYY - xxx Revision

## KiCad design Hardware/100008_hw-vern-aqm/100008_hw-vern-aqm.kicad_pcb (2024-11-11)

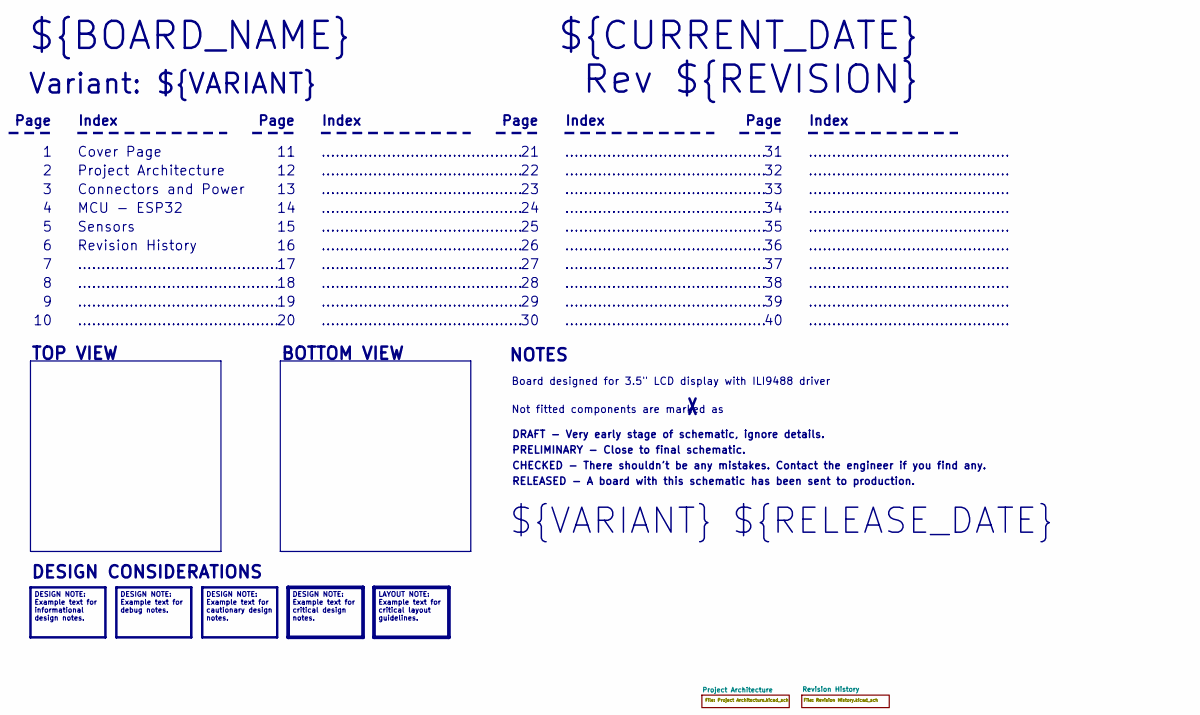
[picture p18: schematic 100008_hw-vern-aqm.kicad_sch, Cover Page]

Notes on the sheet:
DESIGN NOTE: Example text for informational design notes.
LAYOUT NOTE: Example text for critical layout guidelines.
DESIGN NOTE: Example text for cautionary design notes.
DESIGN NOTE: Example text for debug notes.
DESIGN NOTE: Example text for critical design notes.
BOTTOM VIEW
...........................................
RELEASED - A board with this schematic has been sent to production.
Page
TOP VIEW
Not fitted components are marked as
Index
PRELIMINARY - Close to final schematic.
${VARIANT} ${RELEASE_DATE}
Connectors and Power
Board designed for 3.5" LCD display with ILI9488 driver
${CURRENT_DATE}
Variant: ${VARIANT}
Rev ${REVISION}
MCU - ESP32
${BOARD_NAME}
DRAFT - Very early stage of schematic, ignore details.
Sensors
Project Architecture
Cover Page
NOTES
CHECKED - There shouldn't be any mistakes. Contact the engineer if you find any.
DESIGN CONSIDERATIONS
Revision History

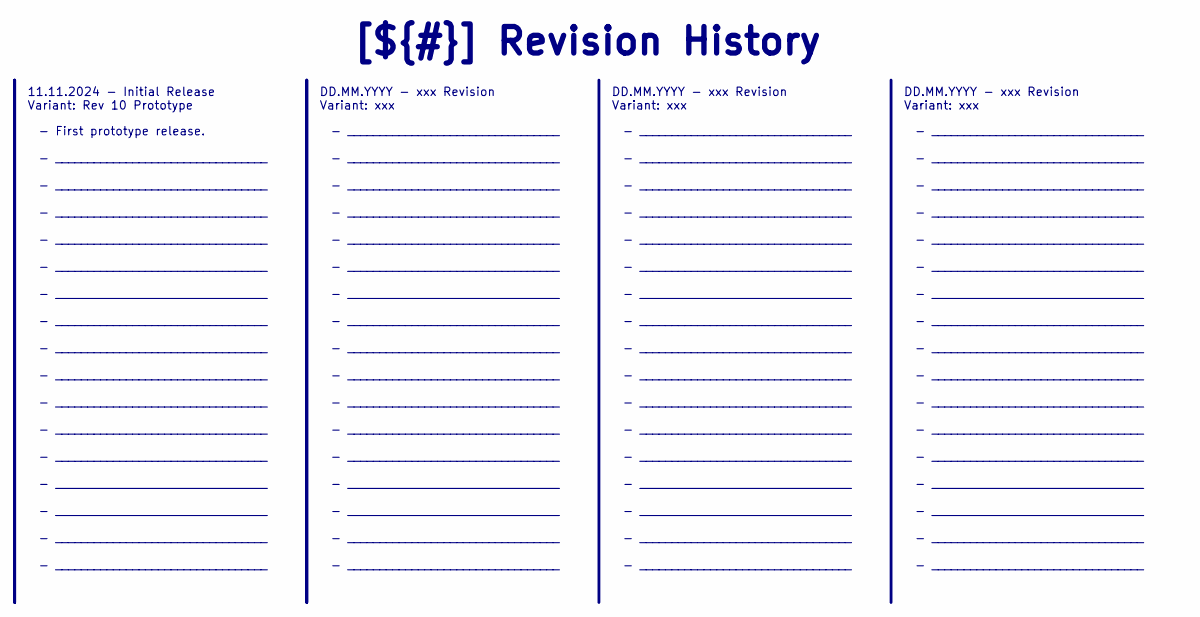
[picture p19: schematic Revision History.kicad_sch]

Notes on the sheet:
- _________________________________ - _________________________________ - _________________________________ - _________________________________ - _________________________________ - _________________________________ - _________________________________ - _________________________________ - _________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
DD.MM.YYYY - xxx Revision Variant: xxx
[${#}] ${TITLE}
- First prototype release. - _________________________________ - _________________________________ - _________________________________ - _________________________________ - _________________________________ - _________________________________ - _________________________________ - __________________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
11.11.2024 - Initial Release Variant: Rev 10 Prototype

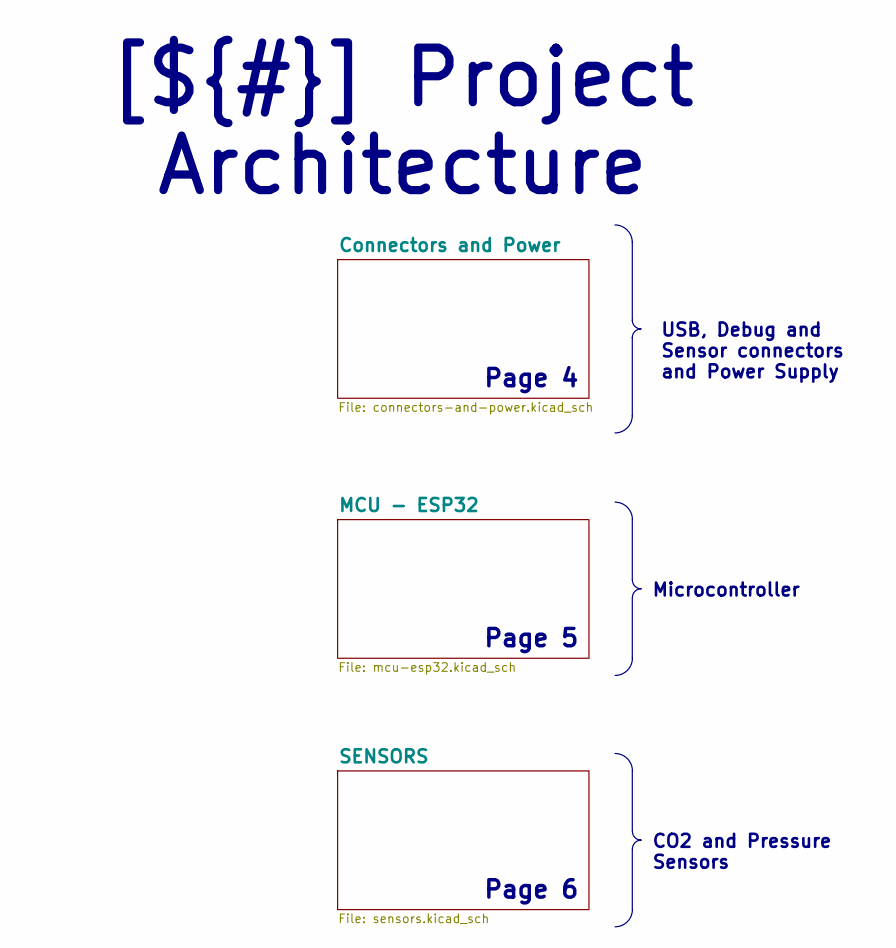
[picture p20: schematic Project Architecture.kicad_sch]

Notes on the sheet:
USB, Debug and Sensor connectors and Power Supply
[${#}] ${TITLE}
CO2 and Pressure Sensors
Microcontroller
Page 6
Page 4
Page 5

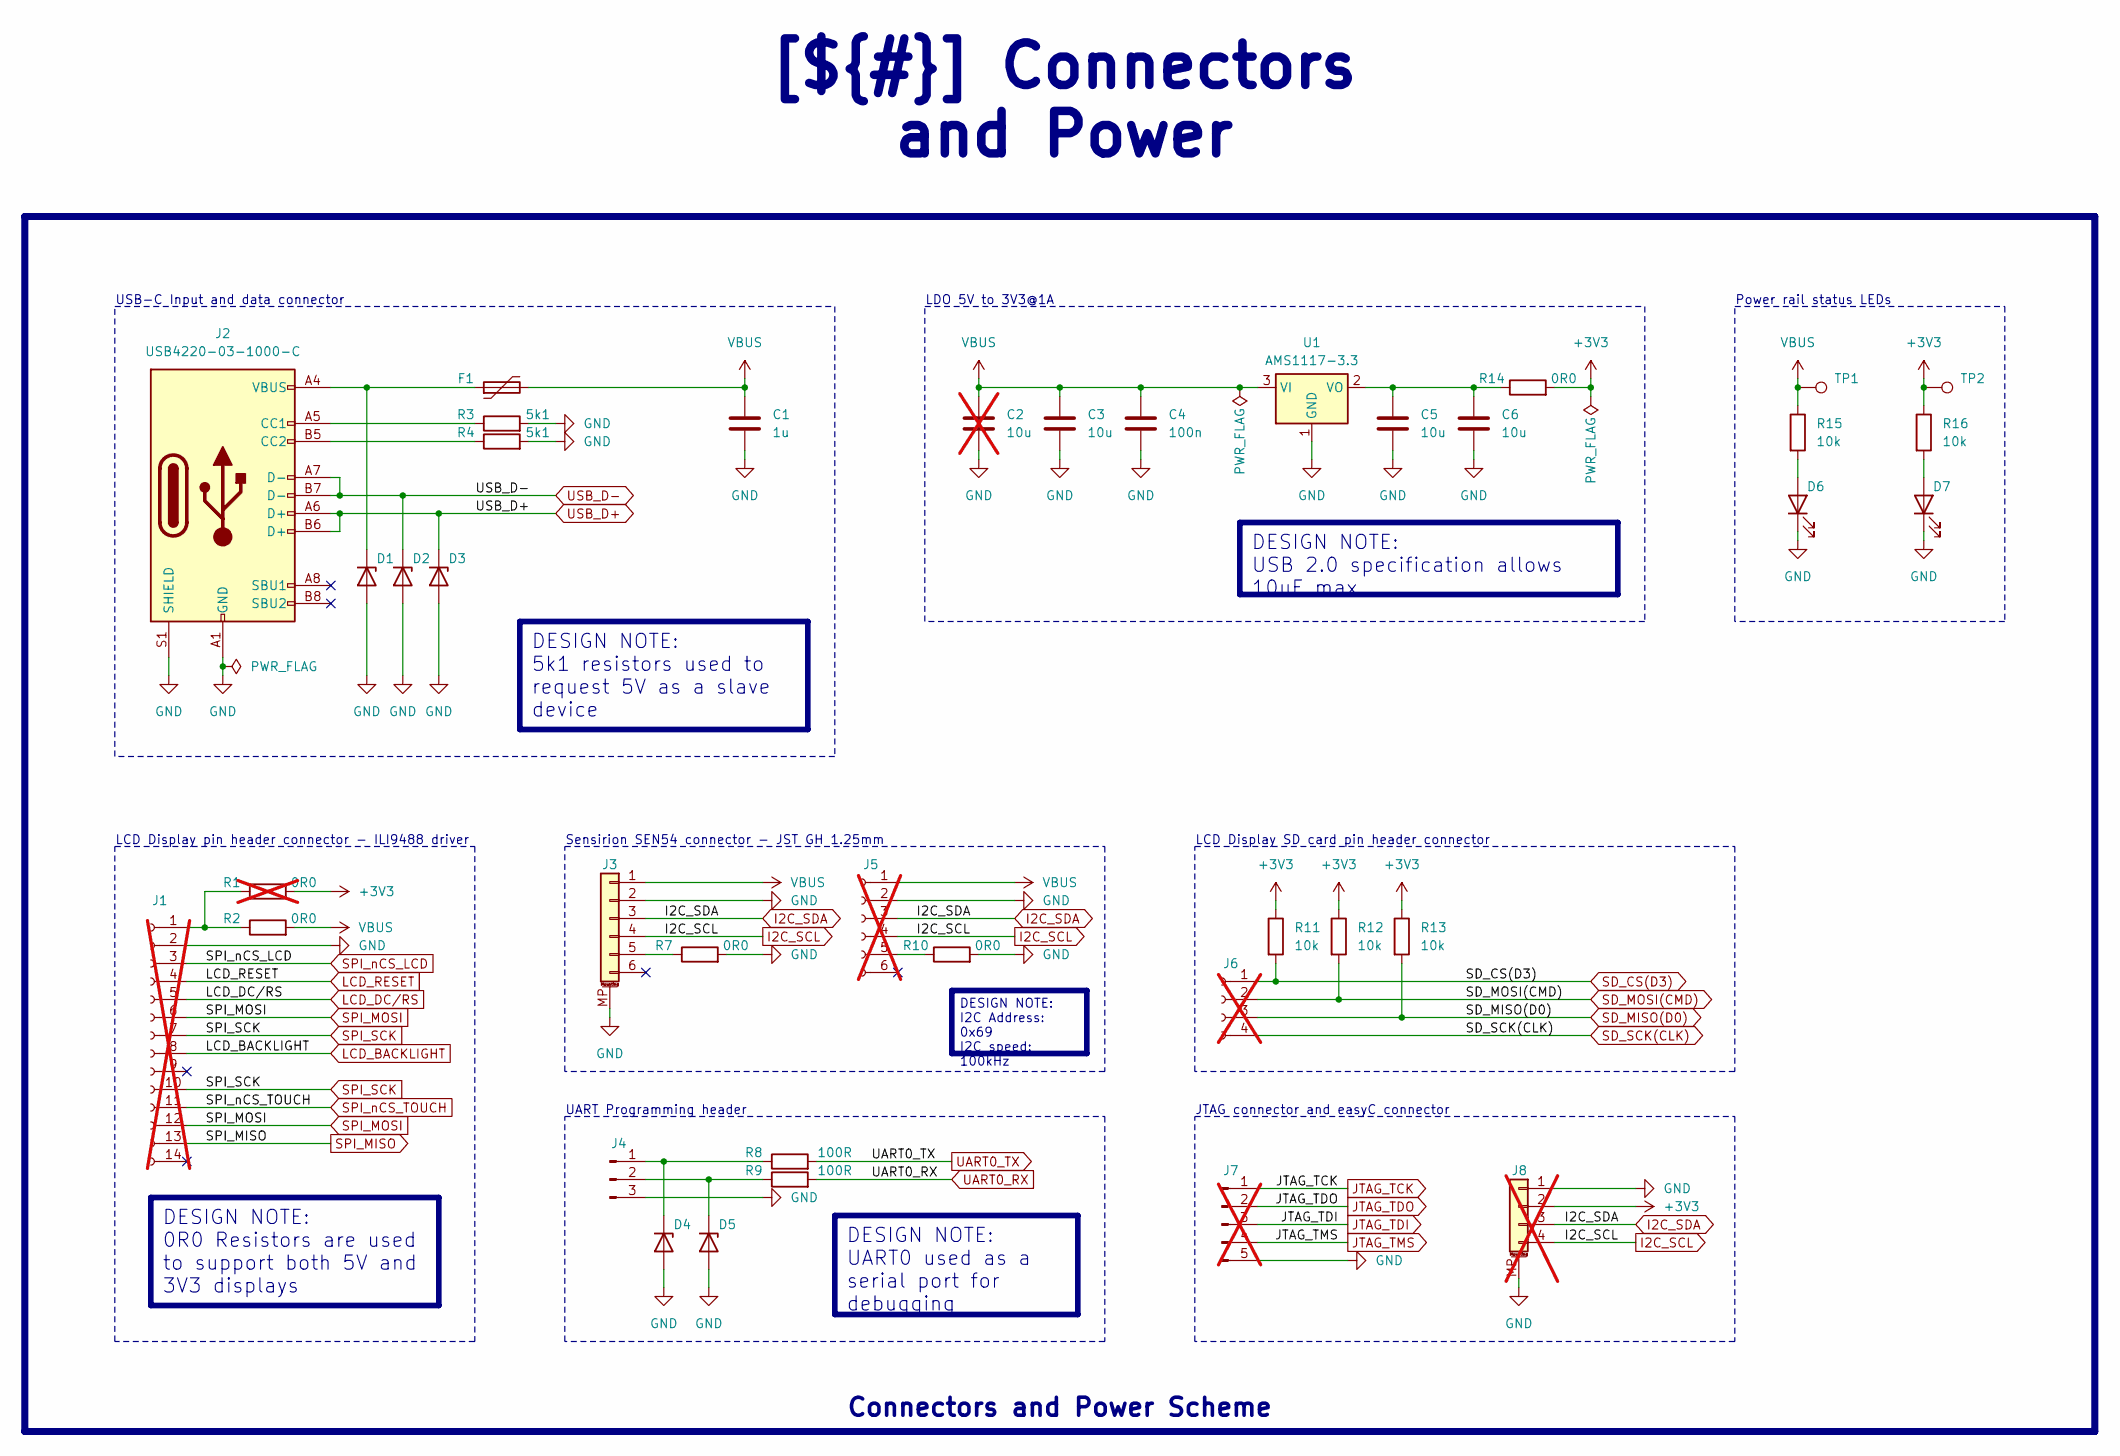
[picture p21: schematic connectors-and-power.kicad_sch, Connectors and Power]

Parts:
C1: 1u; C_0805_2012Metric
C2: 10u; C_0805_2012Metric; not fitted
C3, C5, C6: 10u; C_0805_2012Metric
C4: 100n; C_0603_1608Metric
D1: ESD5Z3V3; D_SOD-523
D2, D3, D4, D5: ESD321DYAR; D_SOD-523
D6, D7: LED; LED_0603_1608Metric
F1: Polyfuse; Fuse_1206_3216Metric
J1: Conn_01x14_Socket; PinHeader_1x14_P2.54mm_Vertical; not fitted
J2: USB4220-03-1000-C; USB_C_Receptacle_GCT_USB4220-03-xxxx-C_Vertical
J3: Conn_01x06_MountingPin; JST_GH_BM06B-GHS-TBT_1x06-1MP_P1.25mm_Vertical
J4: Conn_01x03_Pin; PinHeader_1x03_P2.54mm_Vertical
J5: Conn_01x06_Socket; PinHeader_1x06_P2.00mm_Vertical; not fitted
J6: Conn_01x04_Socket; PinHeader_1x04_P2.54mm_Vertical; not fitted
J7: Conn_01x05_Pin; PinHeader_1x05_P2.54mm_Vertical; not fitted
J8: Conn_01x04_MountingPin; JST_SH_SM04B-SRSS-TB_1x04-1MP_P1.00mm_Horizontal; not fitted
R1: 0R0; R_0603_1608Metric; not fitted
R2, R7, R10, R14: 0R0; R_0603_1608Metric
R3, R4: 5k1; R_0603_1608Metric
R8, R9: 100R; R_0603_1608Metric
R11, R12, R13, R15, R16: 10k; R_0603_1608Metric
TP1, TP2: TestPoint; TestPoint_Pad_D1.5mm
U1: AMS1117-3.3; SOT-223-3_TabPin2

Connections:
+3V3: J8.2, R1.2, R11.1, R12.1, R13.1, R14.2, R16.1, TP2.1; also elsewhere on the board
GND: C1.2, C2.2, C3.2, C4.2, C5.2, C6.2, D1.2 (A), D2.2 (A), D3.2 (A), D4.2 (A), D5.2 (A), D6.1 (K), D7.1 (K), J1.2, J2.A1 (GND), J2.A12 (GND), J2.B1 (GND), J2.B12 (GND), J2.S1 (SHIELD), J3.2, J3.MP (MountPin), J4.3, J5.2, J7.5, J8.1, J8.MP (MountPin), R3.2, R4.2, R7.2, R10.2, U1.1 (GND); also elsewhere on the board
I2C_SCL: J3.4, J5.4, J8.4; also elsewhere on the board
I2C_SDA: J3.3, J5.3, J8.3; also elsewhere on the board
JTAG_TCK: J7.1; also elsewhere on the board
JTAG_TDI: J7.3; also elsewhere on the board
JTAG_TDO: J7.2; also elsewhere on the board
JTAG_TMS: J7.4; also elsewhere on the board
LCD_BACKLIGHT: J1.8; also elsewhere on the board
LCD_DC/RS: J1.5; also elsewhere on the board
LCD_RESET: J1.4; also elsewhere on the board
unnamed: D1.1 (K), F1.1, J2.A4 (VBUS), J2.A9 (VBUS), J2.B4 (VBUS), J2.B9 (VBUS)
unnamed: D4.1 (K), J4.1, R8.1
unnamed: D5.1 (K), J4.2, R9.1
unnamed: D6.2 (A), R15.2
unnamed: D7.2 (A), R16.2
unnamed: J1.1, R1.1, R2.1
unnamed: J2.A5 (CC1), R3.1
unnamed: J2.B5 (CC2), R4.1
unnamed: J3.5, R7.1
unnamed: J5.5, R10.1
unnamed: C5.1, C6.1, R14.1, U1.2 (VO)
SD_CS(D3): J6.1, R11.2; also elsewhere on the board
SD_MISO(D0): J6.3, R13.2; also elsewhere on the board
SD_MOSI(CMD): J6.2, R12.2; also elsewhere on the board
SD_SCK(CLK): J6.4; also elsewhere on the board
SPI_MISO: J1.13; also elsewhere on the board
SPI_MOSI: J1.6, J1.12; also elsewhere on the board
SPI_SCK: J1.7, J1.10; also elsewhere on the board
SPI_nCS_LCD: J1.3; also elsewhere on the board
SPI_nCS_TOUCH: J1.11; also elsewhere on the board
UART0_RX: R9.2; also elsewhere on the board
UART0_TX: R8.2; also elsewhere on the board
USB_D+: D3.1 (K), J2.A6 (D+), J2.B6 (D+); also elsewhere on the board
USB_D-: D2.1 (K), J2.A7 (D-), J2.B7 (D-); also elsewhere on the board
VBUS: C1.1, C2.1, C3.1, C4.1, F1.2, J3.1, J5.1, R2.2, R15.1, TP1.1, U1.3 (VI); also elsewhere on the board

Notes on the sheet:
DESIGN NOTE: USB 2.0 specification allows 10uF max.
DESIGN NOTE: 5k1 resistors used to request 5V as a slave device
DESIGN NOTE: 0R0 Resistors are used to support both 5V and 3V3 displays
DESIGN NOTE: UART0 used as a serial port for debugging
[${#}] ${TITLE}
Connectors and Power Scheme
DESIGN NOTE: I2C Address: 0x69 I2C speed: 100kHz
Power rail status LEDs
LCD Display SD card pin header connector
Sensirion SEN54 connector - JST GH 1.25mm
JTAG connector and easyC connector
UART Programming header
LCD Display pin header connector - ILI9488 driver
LDO 5V to 3V3@1A
USB-C Input and data connector

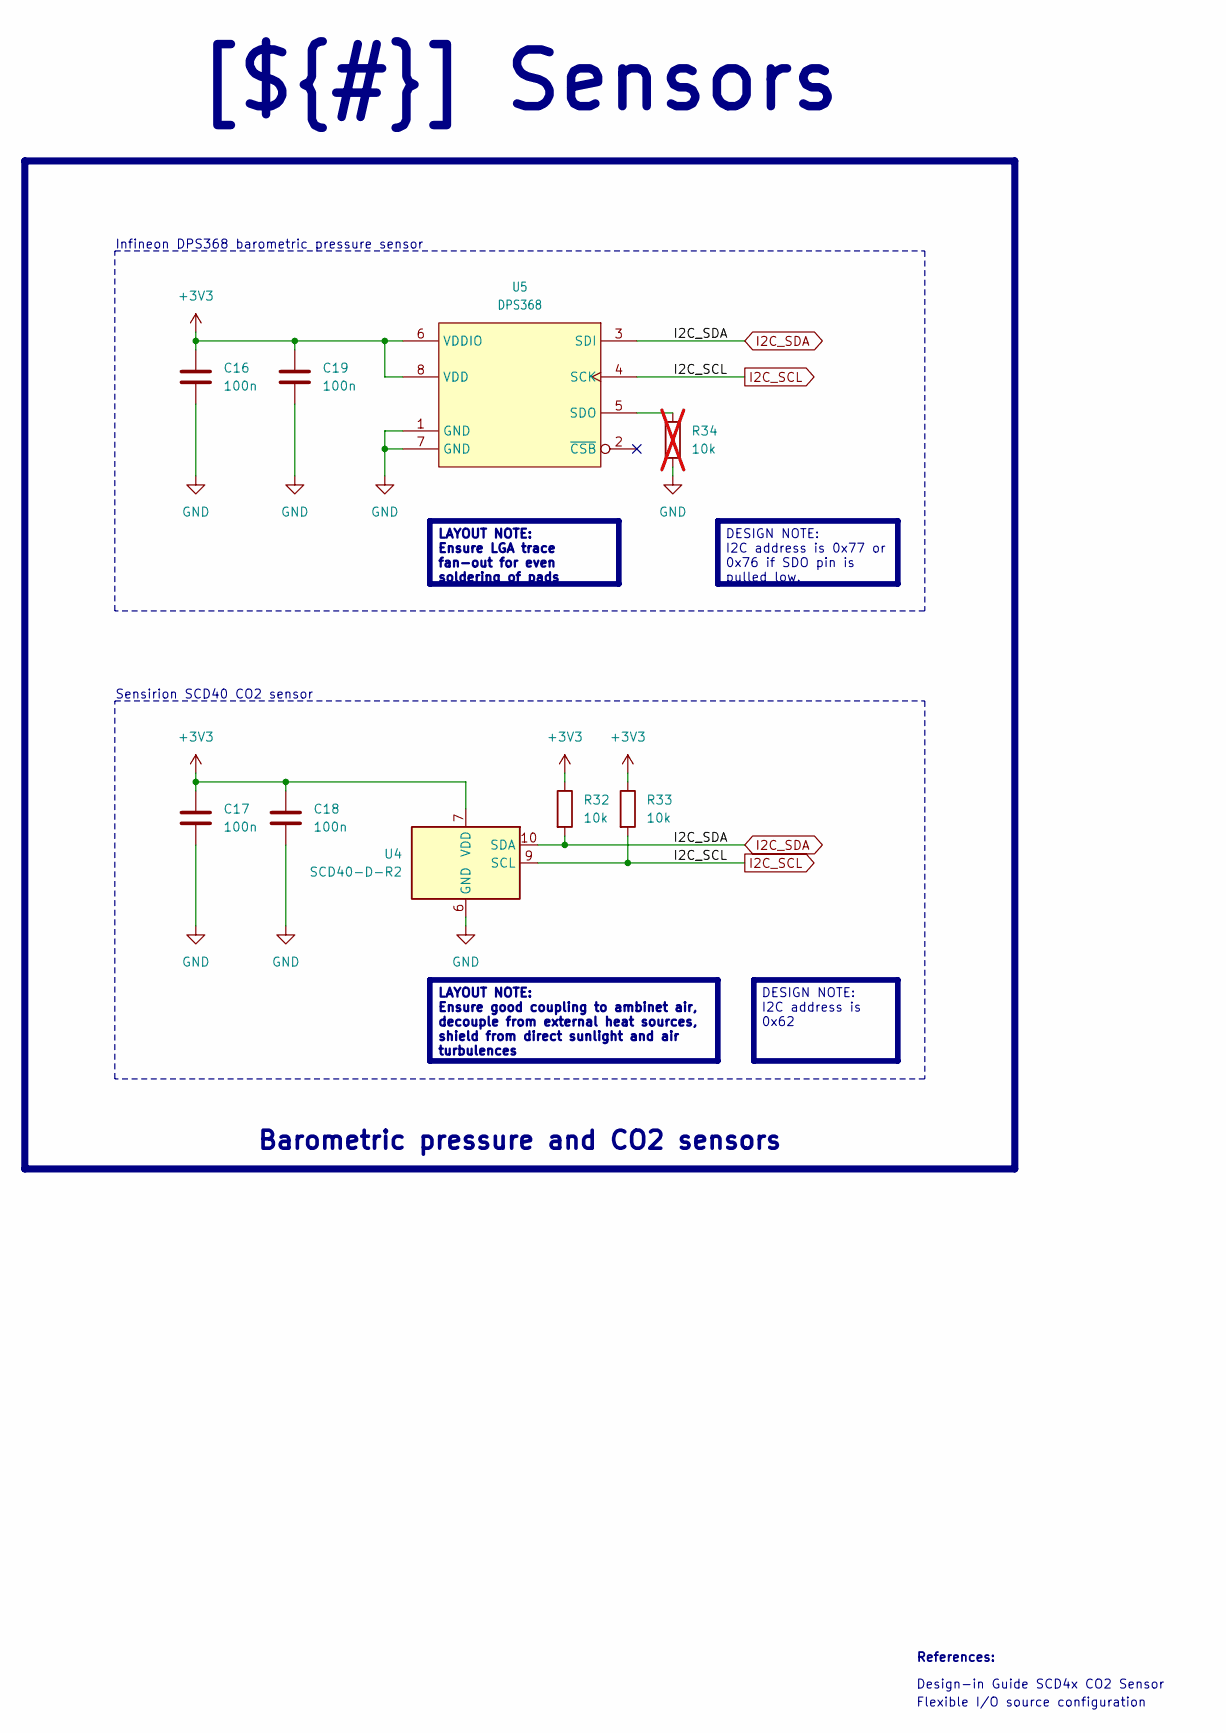
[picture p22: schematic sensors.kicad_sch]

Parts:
C16, C17, C18, C19: 100n; C_0603_1608Metric
R32, R33: 10k; R_0603_1608Metric
R34: 10k; R_0603_1608Metric; not fitted
U4: SCD40-D-R2; Sensirion_SCD4x-1EP_10.1x10.1mm_P1.25mm_EP4.8x4.8mm
U5: DPS368; LGA8S145X65P2X4_200X250X110-V

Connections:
+3V3: C16.1, C17.1, C18.1, C19.1, R32.1, R33.1, U4.7 (VDD), U4.19 (VDD), U5.6 (VDDIO), U5.8 (VDD); also elsewhere on the board
GND: C16.2, C17.2, C18.2, C19.2, R34.2, U4.6 (GND), U4.20 (GND), U4.21 (GND), U5.1 (GND), U5.7 (GND); also elsewhere on the board
I2C_SCL: R33.2, U4.9 (SCL), U5.4 (SCK); also elsewhere on the board
I2C_SDA: R32.2, U4.10 (SDA), U5.3 (SDI); also elsewhere on the board
unnamed: R34.1, U5.5 (SDO)

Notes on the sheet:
[${#}] ${TITLE}
LAYOUT NOTE: Ensure good coupling to ambinet air, decouple from external heat sources, shield from direct sunlight and air turbulences
LAYOUT NOTE: Ensure LGA trace fan-out for even soldering of pads
Barometric pressure and CO2 sensors
DESIGN NOTE: I2C address is 0x62
DESIGN NOTE: I2C address is 0x77 or 0x76 if SDO pin is pulled low.
Design-in Guide SCD4x CO2 Sensor
Infineon DPS368 barometric pressure sensor
Sensirion SCD40 CO2 sensor
References:
Flexible I/O source configuration

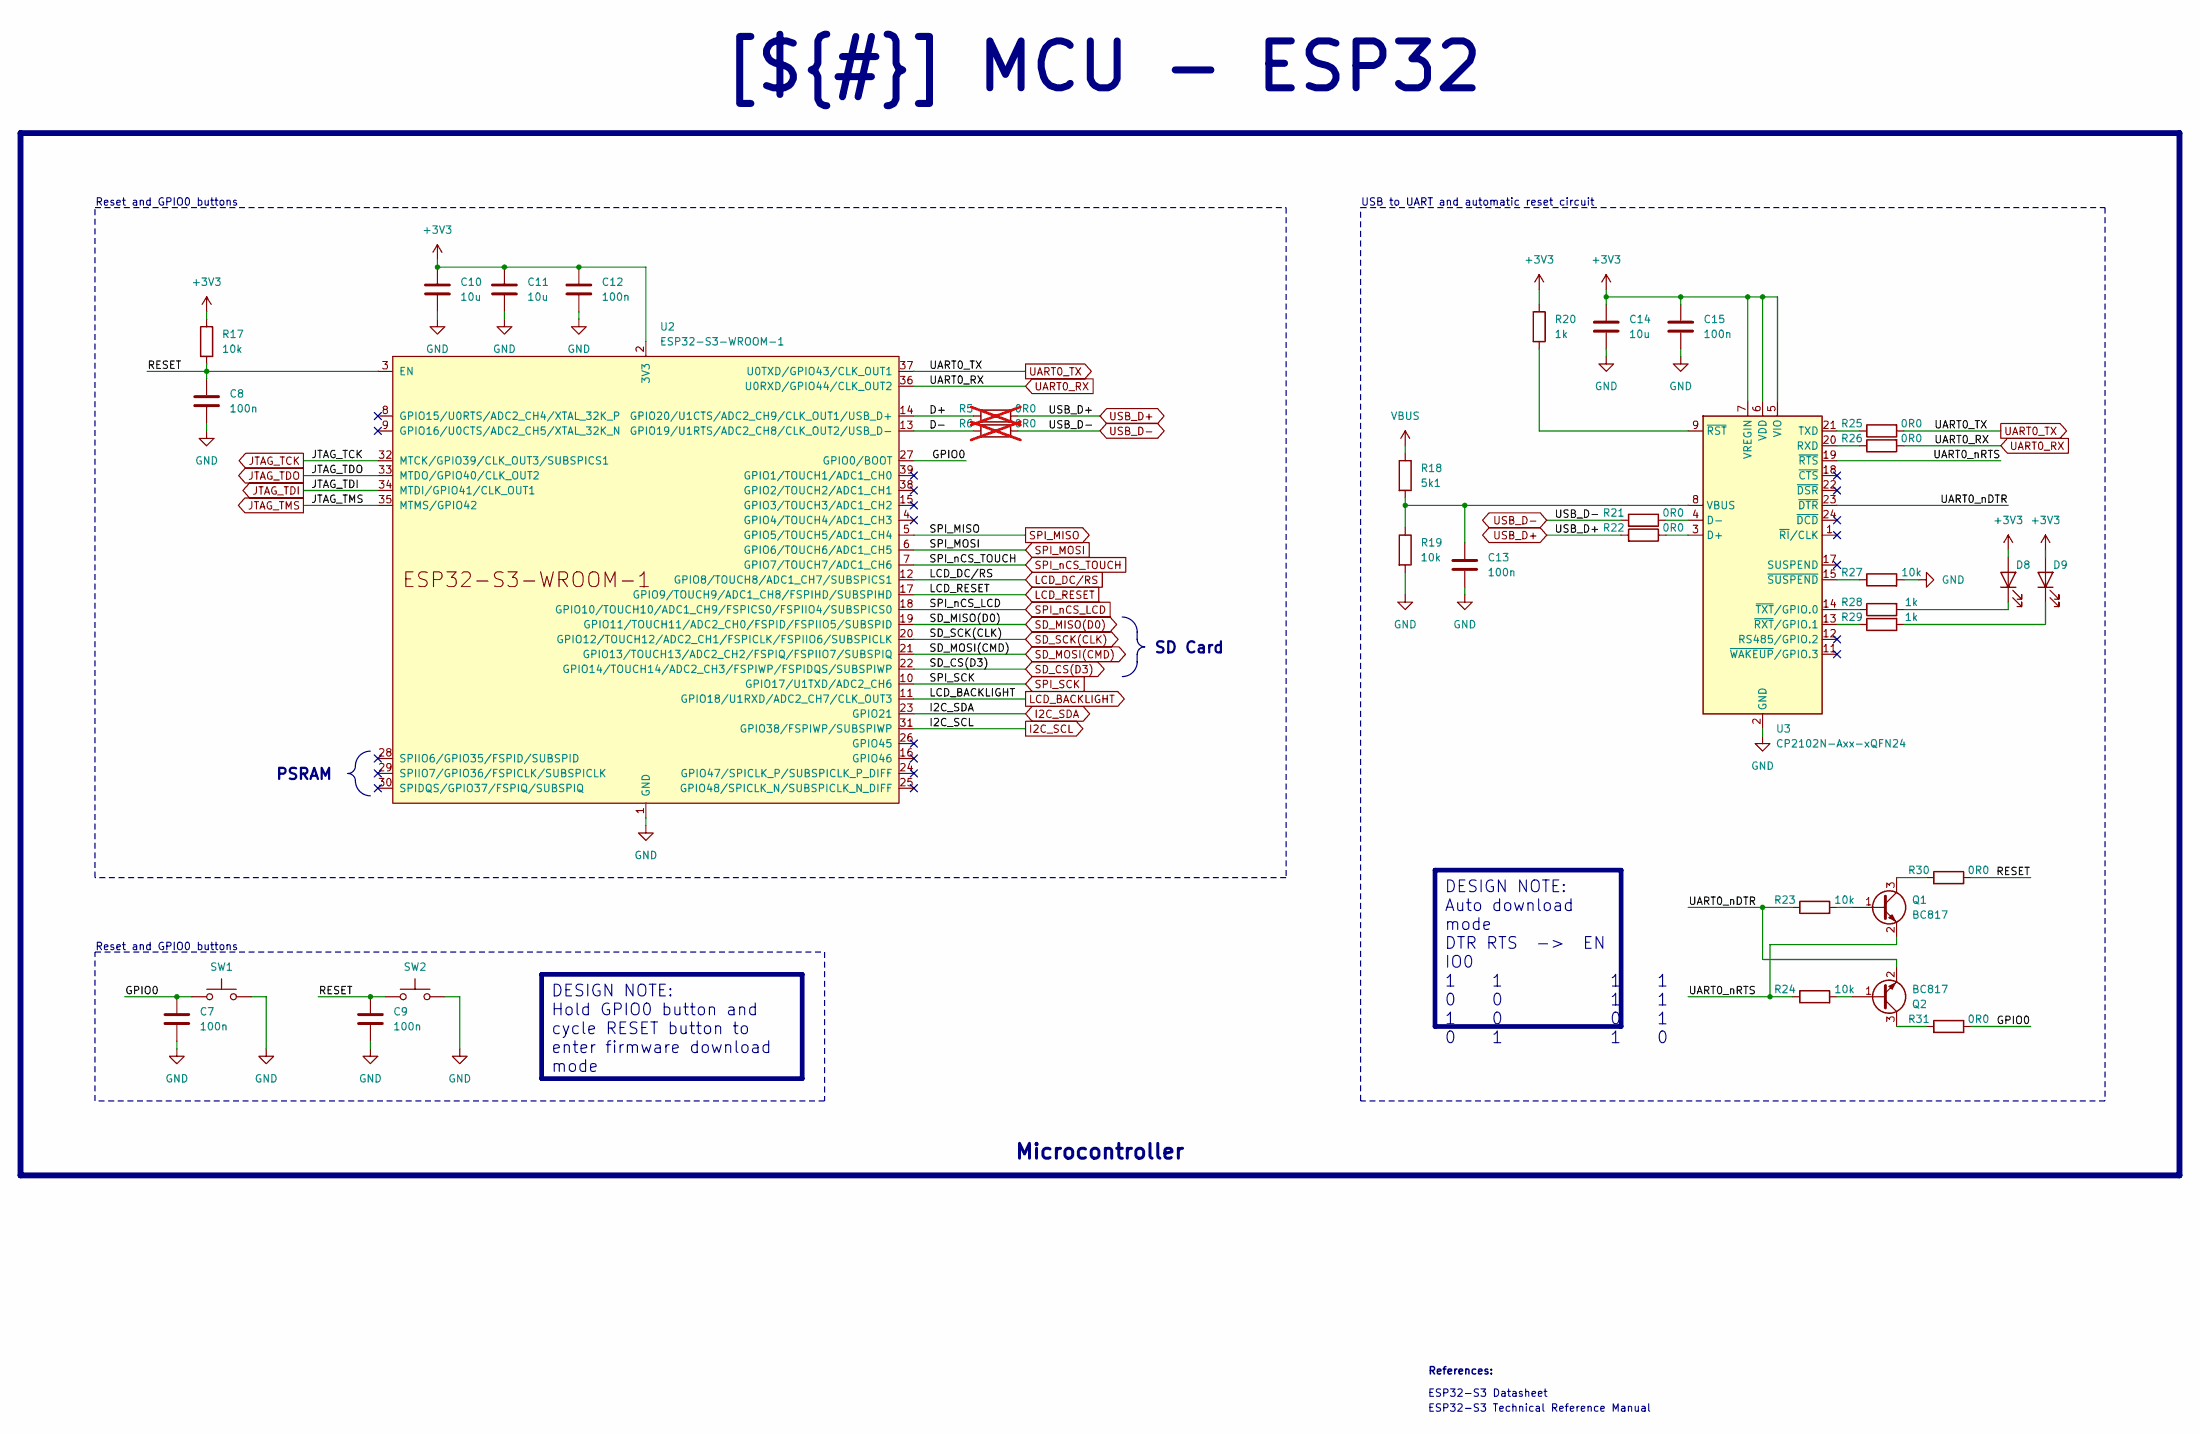
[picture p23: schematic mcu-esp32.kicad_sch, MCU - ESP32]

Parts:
C7, C8, C9, C12, C13, C15: 100n; C_0603_1608Metric
C10, C11, C14: 10u; C_0805_2012Metric
D8, D9: LED; LED_0603_1608Metric
Q1, Q2: BC817; SOT-323_SC-70
R5, R6: 0R0; R_0603_1608Metric; not fitted
R17, R19, R23, R24, R27: 10k; R_0603_1608Metric
R18: 5k1; R_0603_1608Metric
R20, R28, R29: 1k; R_0603_1608Metric
R21, R22, R25, R26, R30, R31: 0R0; R_0603_1608Metric
SW1, SW2: SW_Push; SW_Tactile_SPST_NO_Straight_CK_PTS636Sx25SMTRLFS
U2: ESP32-S3-WROOM-1
U3: CP2102N-Axx-xQFN24; QFN-24-1EP_4x4mm_P0.5mm_EP2.6x2.6mm

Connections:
+3V3: C10.1, C11.1, C12.1, C14.1, C15.1, D8.2 (A), D9.2 (A), R17.1, R20.1, U2.2 (3V3), U3.5 (VIO), U3.6 (VDD), U3.7 (VREGIN); also elsewhere on the board
/Project Architecture/MCU - ESP32/D+: R5.2, U2.14 (GPIO20/U1CTS/ADC2_CH9/CLK_OUT1/USB_D+)
/Project Architecture/MCU - ESP32/D-: R6.2, U2.13 (GPIO19/U1RTS/ADC2_CH8/CLK_OUT2/USB_D-)
/Project Architecture/MCU - ESP32/GPIO0: C7.1, R31.1, SW1.1, U2.27 (GPIO0/BOOT)
/Project Architecture/MCU - ESP32/RESET: C8.1, C9.1, R17.2, R30.1, SW2.1, U2.3 (EN)
/Project Architecture/MCU - ESP32/UART0_nDTR: Q2.2 (E), R23.1, U3.23 (~DTR)
/Project Architecture/MCU - ESP32/UART0_nRTS: Q1.2 (E), R24.1, U3.19 (~RTS)
GND: C7.2, C8.2, C9.2, C10.2, C11.2, C12.2, C13.2, C14.2, C15.2, R19.2, R27.2, SW1.2, SW2.2, U2.1 (GND), U2.40 (GND), U2.41 (GND), U3.2 (GND), U3.25 (GND); also elsewhere on the board
I2C_SCL: U2.31 (GPIO38/FSPIWP/SUBSPIWP); also elsewhere on the board
I2C_SDA: U2.23 (GPIO21); also elsewhere on the board
JTAG_TCK: U2.32 (MTCK/GPIO39/CLK_OUT3/SUBSPICS1); also elsewhere on the board
JTAG_TDI: U2.34 (MTDI/GPIO41/CLK_OUT1); also elsewhere on the board
JTAG_TDO: U2.33 (MTDO/GPIO40/CLK_OUT2); also elsewhere on the board
JTAG_TMS: U2.35 (MTMS/GPIO42); also elsewhere on the board
LCD_BACKLIGHT: U2.11 (GPIO18/U1RXD/ADC2_CH7/CLK_OUT3); also elsewhere on the board
LCD_DC/RS: U2.12 (GPIO8/TOUCH8/ADC1_CH7/SUBSPICS1); also elsewhere on the board
LCD_RESET: U2.17 (GPIO9/TOUCH9/ADC1_CH8/FSPIHD/SUBSPIHD); also elsewhere on the board
unnamed: D8.1 (K), R28.2
unnamed: D9.1 (K), R29.2
unnamed: Q1.1 (B), R23.2
unnamed: Q1.3 (C), R30.2
unnamed: Q2.1 (B), R24.2
unnamed: Q2.3 (C), R31.2
unnamed: R22.1, U3.3 (D+)
unnamed: R21.1, U3.4 (D-)
unnamed: R26.1, U3.20 (RXD)
unnamed: R25.1, U3.21 (TXD)
unnamed: C13.1, R18.2, R19.1, U3.8 (VBUS)
unnamed: R20.2, U3.9 (~RST)
unnamed: R29.1, U3.13 (~RXT/GPIO.1)
unnamed: R27.1, U3.15 (~SUSPEND)
unnamed: R28.1, U3.14 (~TXT/GPIO.0)
SD_CS(D3): U2.22 (GPIO14/TOUCH14/ADC2_CH3/FSPIWP/FSPIDQS/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); also elsewhere on the board
SD_MISO(D0): U2.19 (GPIO11/TOUCH11/ADC2_CH0/FSPID/FSPIIO5/S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); also elsewhere on the board
SD_MOSI(CMD): U2.21 (GPIO13/TOUCH13/ADC2_CH2/FSPIQ/FSPIIO7/S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); also elsewhere on the board
SD_SCK(CLK): U2.20 (GPIO12/TOUCH12/ADC2_CH1/FSPICLK/FSPIIO6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); also elsewhere on the board
SPI_MISO: U2.5 (GPIO5/TOUCH5/ADC1_CH4); also elsewhere on the board
SPI_MOSI: U2.6 (GPIO6/TOUCH6/ADC1_CH5); also elsewhere on the board
SPI_SCK: U2.10 (GPIO17/U1TXD/ADC2_CH6); also elsewhere on the board
SPI_nCS_LCD: U2.18 (GPIO10/TOUCH10/ADC1_CH9/FSPICS0/FSPIIO4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); also elsewhere on the board
SPI_nCS_TOUCH: U2.7 (GPIO7/TOUCH7/ADC1_CH6); also elsewhere on the board
UART0_RX: R26.2, U2.36 (U0RXD/GPIO44/CLK_OUT2); also elsewhere on the board
UART0_TX: R25.2, U2.37 (U0TXD/GPIO43/CLK_OUT1); also elsewhere on the board
USB_D+: R5.1, R22.2; also elsewhere on the board
USB_D-: R6.1, R21.2; also elsewhere on the board
VBUS: R18.1; also elsewhere on the board

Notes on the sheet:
DESIGN NOTE: Auto download mode DTR RTS -> EN IO0 1 1 1 1 0 0 1 1 1 0 0 1 0 1 1 0
DESIGN NOTE: Hold GPIO0 button and cycle RESET button to enter firmware download mode
[${#}] ${TITLE}
SD Card
PSRAM
Microcontroller
Reset and GPIO0 buttons
ESP32-S3 Datasheet
USB to UART and automatic reset circuit
References:
ESP32-S3 Technical Reference Manual

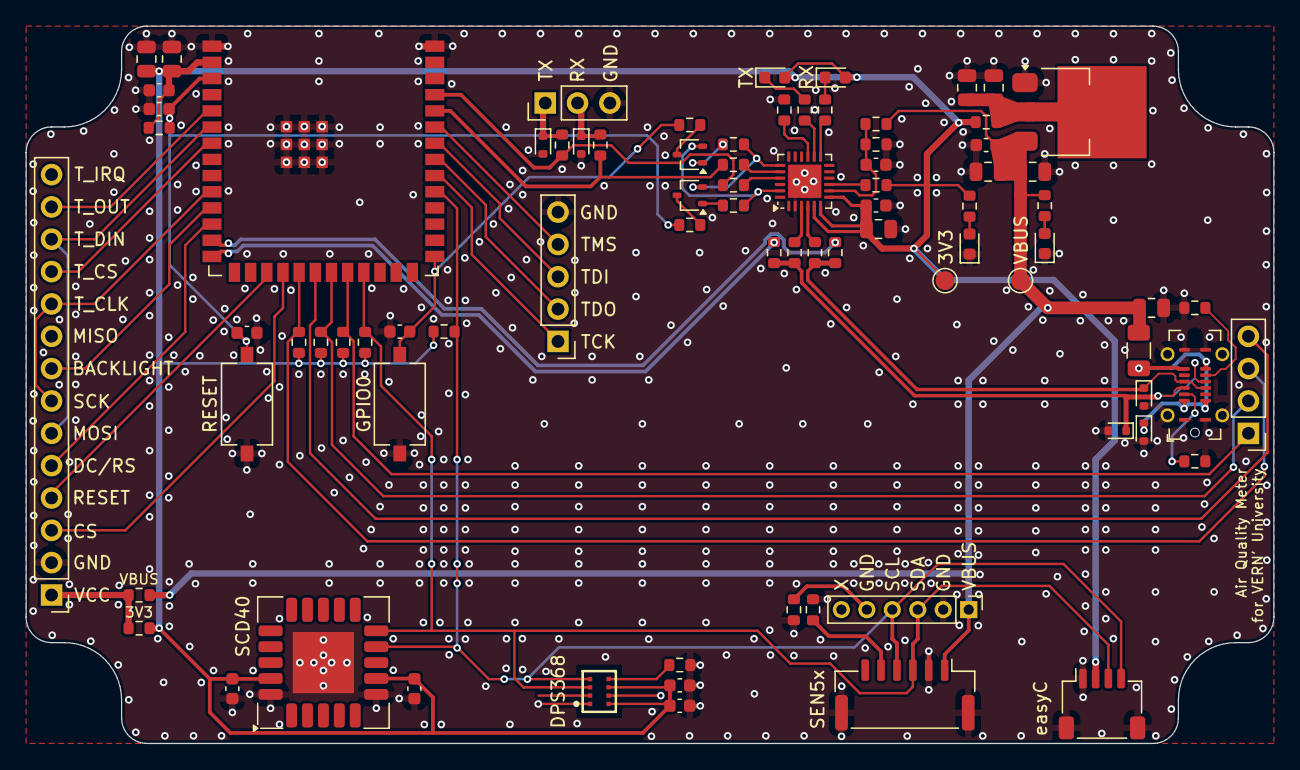
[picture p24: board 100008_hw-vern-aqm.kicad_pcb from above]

Board: 4 copper layers, 98.0 x 56.3 mm, 82 parts (0 on the bottom side), 58 nets.

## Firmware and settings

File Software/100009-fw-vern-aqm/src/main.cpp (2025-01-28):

#include <Arduino.h>
#include <Wire.h>

#include <TFT_eSPI.h>
#include <Dps3xx.h>
#include <SensirionI2CScd4x.h>
#include <SensirionI2CSen5x.h>
#include <SensirionI2cSht4x.h>

#include <WiFi.h>
#include <WiFiUdp.h>
#include <NTPClient.h>
#include <HTTPClient.h>

// Custom code files
#include "secrets.h" // Secret credentials
#include "config.h"  // General configuration
#include "server_functions.h"
#include "lcd_functions.h"

// Display variables - Define which values to display
#define TEMPERATURE sen5xTemperature
#define HUMIDITY sen5xHumidity
#define CO2 scd4xCo2
#define PRESSURE dps368Pressure
#define VOC_INDEX sen5xVocIndex
#define PM1 sen5xPm1
#define PM2_5 sen5xPm2_5
#define PM4 sen5xPm4
#define PM10 sen5xPm10

// Variables for sensor measured values
// SEN5x
float sen5xPm1   = 0.0f;
float sen5xPm2_5 = 0.0f;
float sen5xPm4   = 0.0f;
float sen5xPm10  = 0.0f;
float sen5xHumidity = 0.0f;
float sen5xTemperature = 0.0f;
float sen5xVocIndex = 0.0f;
float sen5xNoxIndex = 0.0f;
// SCD4x
uint16_t scd4xCo2 = 0;
float scd4xTemperature = 0.0f;
float scd4xHumidity = 0.0f;
// DPS368
float dps368Pressure = 0.0f;
float dps368Temperature = 0.0f;
// SHT40 - external sensor
float sht4xTemperature = 0.0f;
float sht4xHumidity = 0.0f;

uint64_t timestamp = 0;

// Creating sensor instances
Dps3xx dps368 = Dps3xx();
SensirionI2CScd4x scd4x = SensirionI2CScd4x();
SensirionI2CSen5x sen5x = SensirionI2CSen5x();
SensirionI2cSht4x sht4x = SensirionI2cSht4x();
// Creating display instances
TFT_eSPI tft = TFT_eSPI();
TFT_eSprite sprite = TFT_eSprite(&tft);
// Creating NTP instances
WiFiUDP ntpUDP;
NTPClient timeClient(ntpUDP, "pool.ntp.org", 3601, 60000); // Update every minute, UTC+1 timezone

String ipString;
String macString;

// Function declarations
// Display functions
void drawWidget(int x, int y, int w, int h, const char* label, const char* value, uint16_t color);
void drawClockAndWiFi();
void updateUI();
void drawUI();

// Sensor functions
void printUint16Hex(uint16_t value);
void printSCD4xSerialNumber();
void printSEN5xSerialNumber();
void printSEN5xModuleVersions();
void printSHT4xSerialNumber();


// Setup function - executes once on power up
void setup() {
    pinMode(BACKLIGHT_PIN, OUTPUT);
    analogWrite(BACKLIGHT_PIN, BRIGHTNESS_VALUE);

    // Initialize serial communication
    Serial.begin(BAUD_RATE);
    while (!Serial) {
        delay(100);
    }
    Serial.println("Booting...");

    // Initialize the display in landscape mode
    tft.init();
    tft.setRotation(3);
    tft.fillScreen(BACKGROUND_COLOR);

    // Create a sprite for the display
    sprite.createSprite(480, 320);

    // Draw UI layout
    drawUI();

    // Initialize WiFi and NTP client
    connectToWifi();
    timeClient.begin();
    IPAddress ip = WiFi.localIP();
    macString = WiFi.macAddress();
    ipString = ip.toString();

    // Draw UI again for the IP address
    drawUI();

    // Initialize I2C bus
    Wire.begin(SDA_PIN, SCL_PIN);
    scd4x.begin(Wire);
    sen5x.begin(Wire);
    dps368.begin(Wire, DPS368_ADDRESS);
    sht4x.begin(Wire, SHT4X_ADDRESS);

    delay(100);

    // SCD4x Initialization
    // Stop SCD4x potentially previously started measurement
    uint16_t scd4xError;
    char scd4xErrorMessage[256];
    scd4xError = scd4x.stopPeriodicMeasurement();
    if (scd4xError) {
        Serial.print("Error trying to execute scd4x.stopPeriodicMeasurement(): ");
        errorToString(scd4xError, scd4xErrorMessage, 256);
        Serial.println(scd4xErrorMessage);
    }

    // SEN5x Initialization
    // Reset SEN5x 
    uint16_t sen5xError;
    char sen5xErrorMessage[256];
    sen5xError = sen5x.deviceReset();
    if (sen5xError != 0 && DEBUG_SERIAL == 1) {
        Serial.print("Error trying to execute sen5x.deviceReset(): ");
        errorToString(sen5xError, sen5xErrorMessage, 256);
        Serial.println(sen5xErrorMessage);
    }

    // SHT4x Initialization
    // Reset SHT4x 
    uint16_t sht4xError;
    char sht4xErrorMessage[64];
    sht4xError = sht4x.softReset();
    if (sht4xError != 0 && DEBUG_SERIAL == 1) {
        Serial.print("Error trying to execute sht4x.softReset(): ");
        errorToString(sht4xError, sht4xErrorMessage, 64);
        Serial.println(sht4xErrorMessage);
    }

    // Print sensor module information if I2C buffers are set 
    #ifdef USE_PRODUCT_INFO
        if (DEBUG_SERIAL == 1) {
        printSHT4xSerialNumber();
        printSCD4xSerialNumber();
        printSEN5xModuleVersions();
        // Add ambient pressure sensor
        }
    #endif

    #ifdef SEN5X_TEMP_OFFSET
        // Set temperature offset for SEN5x
        sen5xError = sen5x.setTemperatureOffsetSimple(SEN5X_TEMP_OFFSET);
        if (sen5xError != 0 && DEBUG_SERIAL == 1) {
            Serial.print("Error trying to execute sen5x.setTemperatureOffsetSimple(): ");
            errorToString(sen5xError, sen5xErrorMessage, 256);
            Serial.println(sen5xErrorMessage);
        } 
        else if (sen5xError == 0 && DEBUG_SERIAL == 1) {
            Serial.print("SEN5x Temperature Offset set to: ");
            Serial.print(SEN5X_TEMP_OFFSET);
            Serial.println(" °C (SEN54/SEN55 only)");
        }
    #endif

    // Start SCD4x measurement
    scd4xError = scd4x.startPeriodicMeasurement();
    if (scd4xError != 0 && DEBUG_SERIAL == 1) {
        Serial.print("Error trying to execute scd4x.startPeriodicMeasurement(): ");
        errorToString(scd4xError, scd4xErrorMessage, 256);
        Serial.println(scd4xErrorMessage);
    }
    
    // Set SEN5x Auto Cleaning Interval
    sen5xError = sen5x.setFanAutoCleaningInterval(SEN5X_CLEANING_INTERVAL);
    if (sen5xError) {
        errorToString(sen5xError, sen5xErrorMessage, 256);
            Serial.println(sen5xErrorMessage);
    }

    // Serial print SEN5x Auto Cleaning Interval
    uint32_t interval;
    sen5xError = sen5x.getFanAutoCleaningInterval(interval);
    if (sen5xError != 0 && DEBUG_SERIAL == 1) {
        Serial.print("Error trying to execute sen5x.getFanAutoCleaningInterval(): ");
        errorToString(sen5xError, sen5xErrorMessage, 256);
        Serial.println(sen5xErrorMessage);
    } else {
        Serial.print("SEN5x Auto Cleaning Interval set to: "); Serial.print(interval); Serial.println(" sec");
    }

    // Start SEN5x measurement
    sen5xError = sen5x.startMeasurement();
    if (sen5xError != 0 && DEBUG_SERIAL == 1) {
        Serial.print("Error trying to execute sen5x.startMeasurement(): ");
        errorToString(sen5xError, sen5xErrorMessage, 256);
        Serial.println(sen5xErrorMessage);
    }

    /*##############################################
    ##  add external sensor initializations here  ##
    ##############################################*/

    if (DEBUG_SERIAL == 1) {
        Serial.println("Booting process completed ");
        Serial.println("Waiting for first measurement... (5 sec)");
    }

}

// Main loop function - executes in loop after setup function is executed
void loop() {
    timeClient.update();
    // Refresh UI
    updateUI();

    // SCD4x
    // Check if SCD4x is ready to send data
    bool isDataReady = false;
    uint16_t scd4xError;
    char scd4xErrorMessage[256];
    scd4xError = scd4x.getDataReadyFlag(isDataReady);
    if (scd4xError != 0 && DEBUG_SERIAL == 1) {
        Serial.print("Error trying to execute scd4x.getDataReadyFlag(): ");
        errorToString(scd4xError, scd4xErrorMessage, 256);
        Serial.println(scd4xErrorMessage);
        return;
    }
    if (!isDataReady) {
        return;
    }
    // Read and serial print SCD4x measurements

    if (DEBUG_SERIAL == 1) {
        Serial.println("-----------------------");
        Serial.println("SCD4x Measurements:");
    }
    scd4xError = scd4x.readMeasurement(scd4xCo2, scd4xTemperature, scd4xHumidity);
    if (scd4xError != 0 && DEBUG_SERIAL == 1) {
        Serial.print("Error trying to execute scd4x.readMeasurement(): ");
        errorToString(scd4xError, scd4xErrorMessage, 256);
        Serial.println(scd4xErrorMessage);
    } else if (scd4xCo2 == 0 && DEBUG_SERIAL == 1) {
        Serial.println("SCD4x Invalid sample detected, skipping.");
    } else if (scd4xError == 0 && DEBUG_SERIAL == 1){
        Serial.print("CO2: "); Serial.print(scd4xCo2); Serial.println(" ppm");
        Serial.print("Temperature: "); Serial.print(scd4xTemperature); Serial.println(" °C");
        Serial.print("Humidity: "); Serial.print(scd4xHumidity); Serial.println(" %");
    }

    // SEN5x
    // Read and serial print SEN5x measurements
    if (DEBUG_SERIAL == 1) {
        Serial.println("-----------------------");
        Serial.println("SEN5x Measurements:");
    }
    uint16_t sen5xError;
    char sen5xErrorMessage[256];

    sen5xError = sen5x.readMeasuredValues(
        sen5xPm1,
        sen5xPm2_5,
        sen5xPm4,
        sen5xPm10,
        sen5xHumidity, 
        sen5xTemperature, 
        sen5xVocIndex,
        sen5xNoxIndex);

    if (sen5xError != 0 && DEBUG_SERIAL == 1) {
        Serial.print("Error trying to execute sen5x.readMeasuredValues(): ");
        errorToString(sen5xError, sen5xErrorMessage, 256);
        Serial.println(sen5xErrorMessage);
    } else if (sen5xError == 0 && DEBUG_SERIAL == 1) {
        Serial.print("PM 1.0: "); Serial.print(sen5xPm1);   Serial.println(" µg/m³");
        Serial.print("PM 2.5: "); Serial.print(sen5xPm2_5); Serial.println(" µg/m³");
        Serial.print("PM 4.0: "); Serial.print(sen5xPm4);   Serial.println(" µg/m³");
        Serial.print("PM 10: ");  Serial.print(sen5xPm10);  Serial.println(" µg/m³");

        Serial.print("Temperature: ");
        if (isnan(sen5xTemperature)) {
            Serial.println("n/a");
        } else {
            Serial.print(sen5xTemperature); Serial.println(" °C");
        }

        Serial.print("Humidity: ");
        if (isnan(sen5xHumidity)) {
            Serial.println("n/a");
        } else {
            Serial.print(sen5xHumidity); Serial.println(" %");
        }

        Serial.print("VocIndex: ");
        if (isnan(sen5xVocIndex)) {
            Serial.println("n/a");
        } else {
            Serial.println(sen5xVocIndex);
        }

        Serial.print("NoxIndex: ");
        if (isnan(sen5xNoxIndex)) {
            Serial.println("n/a");
        } else {
            Serial.println(sen5xNoxIndex);
        }
    }

    // DPS368
    // Read and serial print DPS368 measurements
    if (DEBUG_SERIAL == 1) {
        Serial.println("-----------------------");
        Serial.println("DPS368 Measurements:");
    }

    int16_t dps368Error;
    dps368Error = dps368.measureTempOnce(dps368Temperature, DPS368_OVERSAMPLING);
    if (dps368Error != 0 && DEBUG_SERIAL == 1) {
        Serial.print("Error trying to execute dps368.measureTempOnce(): "); 
        Serial.println(dps368Error);
    } else if (dps368Error == 0 && DEBUG_SERIAL == 1) {
        Serial.print("Temperature: "); Serial.print(dps368Temperature); Serial.println(" °C");
    }
    
    dps368Error = dps368.measurePressureOnce(dps368Pressure, DPS368_OVERSAMPLING);
    if (dps368Error != 0 && DEBUG_SERIAL == 1) {
        Serial.print("Error trying to execute dps368.measurePressureOnce(): ");
        Serial.println(dps368Error);
    } else if (dps368Error == 0 && DEBUG_SERIAL == 1) {
        Serial.print("Pressure: "); Serial.print(dps368Pressure); Serial.println(" Pa"); 
    }

    // SHT4x
    // Read and serial print SHT4x measurements
    if (DEBUG_SERIAL == 1) {
        Serial.println("-----------------------");
        Serial.println("SHT4x Measurements:");
    }
    int16_t sht4xError;
    char sht4xErrorMessage[64];
    sht4xError = sht4x.measureHighPrecision(sht4xTemperature, sht4xHumidity);
    if (sht4xError != 0 && DEBUG_SERIAL == 1) {
        Serial.print("Error trying to execute sht4x.measureHighPrecision(): ");
        errorToString(sht4xError, sht4xErrorMessage, 64);
        Serial.println(sht4xErrorMessage);
    } else if (sht4xError == 0 && DEBUG_SERIAL == 1) {
        Serial.print("Temperature: "); Serial.print(sht4xTemperature); Serial.println(" °C");
        Serial.print("Humidity: "); Serial.print(sht4xHumidity); Serial.println(" %");
    } else if (sht4xError == 0) {
        
    }

    sendDataToHTTPServer(macString, TEMPERATURE, HUMIDITY, PM1, PM2_5, PM4, PM10, CO2, VOC_INDEX, PRESSURE);

}


// Draw initial UI with Wi-Fi credentials
void drawUI() {
    sprite.fillSprite(BACKGROUND_COLOR);

    drawClockAndWiFi();

    sprite.setTextDatum(TL_DATUM); // Top-left
    sprite.setTextColor(TEXT_COLOR, TOP_BAR_COLOR);
    sprite.setTextSize(3);
    sprite.drawString("Time Zone", 10, 8);

    sprite.setTextDatum(TL_DATUM); // Top-left
    sprite.setTextColor(TEXT_COLOR, BACKGROUND_COLOR);
    sprite.setTextSize(3);
    sprite.drawString("SSID:", 20, 60);  sprite.drawString(SECRET_SSID, 120, 60);
    sprite.drawString("PASS:", 20, 120); sprite.drawString(SECRET_PASSWORD, 120, 120);
    sprite.drawString("IP:", 20, 180); sprite.drawString(ipString, 120, 180);

    sprite.pushSprite(0, 0);

    sprite.fillRect(0,35,480,285, BACKGROUND_COLOR);

    sprite.pushSprite(0, 0);

}

// Draw clock and Wi-Fi indicator
void drawClockAndWiFi() {
    // Draw clock
    unsigned long currentEpoch = timeClient.getEpochTime();
    String currentTime = epochToHoursMinutes(currentEpoch);

    sprite.fillRect(0,0,480,35, TOP_BAR_COLOR);
    sprite.setTextDatum(TC_DATUM); // Top-center
    sprite.setTextColor(TEXT_COLOR, TOP_BAR_COLOR);
    sprite.setTextSize(3);
    sprite.drawString(currentTime, 240, 8);

    // Draw WiFi symbol and indication - TODO
    if (WiFi.status() == WL_CONNECTED) {
        sprite.fillCircle(455, 18, 7, TFT_GREEN); // Indicate WiFi connection (green dot)
    } else {
        sprite.fillCircle(455, 18, 7, TFT_RED); // Indicate NO WiFi connection (red dot)
    }
}

// Draw widgets with specified values
void drawWidget(int x, int y, int w, int h, const char* label, const char* unit, const char* value, uint16_t color) {
    // Draw the rounded rectangle
    sprite.fillRoundRect(x, y, w, h, 10, color);
    sprite.fillRoundRect(x + 5, y + 5, w - 10, h - 10, 5, BACKGROUND_COLOR);

    // Draw the label
    sprite.setTextColor(TEXT_COLOR, BACKGROUND_COLOR);
    sprite.setTextDatum(TC_DATUM);
    sprite.setTextSize(2);
    sprite.drawString(label, x + w / 2, y + 12);

    // Draw the value
    sprite.setTextSize(2);
    sprite.setTextColor(MEASUREMENT_TEXT_COLOR, BACKGROUND_COLOR);
    sprite.drawString(value, x + w / 2, (y + h / 2)-10);

    // Draw the measurement unit
    sprite.setTextColor(TEXT_COLOR, BACKGROUND_COLOR);
    sprite.setTextDatum(TC_DATUM);
    sprite.setTextSize(2);
    sprite.drawString(unit, x + w / 2, y + 80);
}

// Update each widget with new sensor values
void updateUI() {
    uint8_t x = 3;
    uint8_t y = 55;
    uint8_t w = 110;
    uint8_t h = 110;
    uint8_t v_space = 25;

    drawWidget(x +   0, y, w, h, "Temp",     "C",   String(TEMPERATURE, 1).c_str(),  getTempColor(TEMPERATURE));
    drawWidget(x + 120, y, w, h, "RH",       "%",   String(HUMIDITY, 1).c_str(),     getHumidityColor(HUMIDITY));
    drawWidget(x + 240, y, w, h, "CO2",      "ppm", String(CO2).c_str(),             getCO2Color(CO2));
    drawWidget(x + 360, y, w, h, "Pressure", "hPa", String(PRESSURE/100, 2).c_str(), getPressureColor(PRESSURE));

    drawWidget(x +   0, y + h + v_space, w, h, "VOC",   "Index", String(VOC_INDEX, 0).c_str(), getVOCColor(VOC_INDEX));
    drawWidget(x + 120, y + h + v_space, w, h, "PM1",   "ug/m3", String(PM1, 0).c_str(),       getPM1Color(PM1));
    drawWidget(x + 240, y + h + v_space, w, h, "PM2.5", "ug/m3", String(PM2_5, 0).c_str(),     getPM2_5Color(PM2_5));
    drawWidget(x + 360, y + h + v_space, w, h, "PM10",  "ug/m3", String(PM10, 0).c_str(),      getPM10Color(PM10));

    drawClockAndWiFi();

    sprite.pushSprite(0, 0);
}

// Sensor function definition
// Serial print a 16-bit unsigned integer in 4 digit HEX format by adding leading zeros
void printUint16Hex(uint16_t value) {
    Serial.print(value < 4096 ? "0" : "");
    Serial.print(value < 256 ? "0" : "");
    Serial.print(value < 16 ? "0" : "");
    Serial.print(value, HEX);
}

// Serial print the SCD4x serial number using the printUint16Hex number formater function
void printSCD4xSerialNumber() {
    uint16_t serial0;
    uint16_t serial1;
    uint16_t serial2;

    uint16_t error;
    char errorMessage[256];
    error = scd4x.getSerialNumber(serial0, serial1, serial2);
    if (error) {
        Serial.print("Error trying to execute scd4x.getSerialNumber(): ");
        errorToString(error, errorMessage, 256);
        Serial.println(errorMessage);
    } else {
        Serial.print("SCD4x Serial Number: 0x");
        printUint16Hex(serial0);
        printUint16Hex(serial1);
        printUint16Hex(serial2);
        Serial.println();
    }
    
}

// Serial print the SEN5x serial number
void printSEN5xSerialNumber() {
    unsigned char serialNumber[32];
    uint8_t serialNumberSize = 32;

    uint16_t error;
    char errorMessage[256];
    error = sen5x.getSerialNumber(serialNumber, serialNumberSize);
    if (error) {
        Serial.print("Error trying to execute sen5x.getSerialNumber(): ");
        errorToString(error, errorMessage, 256);
        Serial.println(errorMessage);
    } else {
        Serial.print(" Serial Number: ");
        Serial.println((char*)serialNumber);
    }
}

// Serial print the SEN5x serial number, firmware and hardware version
void printSEN5xModuleVersions() {
    unsigned char productName[32];
    uint8_t productNameSize = 32;

    uint16_t error;
    char errorMessage[256];
    error = sen5x.getProductName(productName, productNameSize);
    if (error) {
        Serial.print("Error trying to execute sen5x.getProductName(): ");
        errorToString(error, errorMessage, 256);
        Serial.println(errorMessage);
    } else {
        //Serial.print("ProductName:");
        Serial.print((char*)productName);
        printSEN5xSerialNumber();
    }

    bool firmwareDebug;
    uint8_t firmwareMajor;
    uint8_t firmwareMinor;
    uint8_t hardwareMajor;
    uint8_t hardwareMinor;
    uint8_t protocolMajor;
    uint8_t protocolMinor;

    error = sen5x.getVersion(firmwareMajor, firmwareMinor, firmwareDebug,
                             hardwareMajor, hardwareMinor, protocolMajor,
                             protocolMinor);
    if (error) {
        Serial.print("Error trying to execute sen5x.getVersion(): ");
        errorToString(error, errorMessage, 256);
        Serial.println(errorMessage);
    } else {
        Serial.print("Firmware: ");
        Serial.print(firmwareMajor);
        Serial.print(".");
        Serial.print(firmwareMinor);
        Serial.print(", ");

        Serial.print("Hardware: ");
        Serial.print(hardwareMajor);
        Serial.print(".");
        Serial.println(hardwareMinor);
    }
}

// Serial print the SHT4x serial number
void printSHT4xSerialNumber() {
    uint32_t serialNumber = 0;

    int16_t error;
    char errorMessage[64];
    error = sht4x.serialNumber(serialNumber);
    if (error) {
        Serial.print("Error trying to execute sht4x.serialNumber(): ");
        errorToString(error, errorMessage, 64);
        Serial.println(errorMessage);
    }
    Serial.print("SHT4x Serial Number: "); Serial.println(serialNumber);
}

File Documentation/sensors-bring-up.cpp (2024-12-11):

#include <Arduino.h>
#include <Wire.h>
#include <Dps3xx.h>
#include <SensirionI2CScd4x.h>
#include <SensirionI2CSen5x.h>

#define MAXBUF_REQUIREMENT 48 // The used commands use up to 48 bytes.
#if (defined(I2C_BUFFER_LENGTH) &&                 \
     (I2C_BUFFER_LENGTH >= MAXBUF_REQUIREMENT)) || \
    (defined(BUFFER_LENGTH) && BUFFER_LENGTH >= MAXBUF_REQUIREMENT)
#define USE_PRODUCT_INFO
#endif

// configuration
#define BAUD_RATE 115200
#define SEN5X_TEMP_OFFSET 0.0
#define DPS368_OVERSAMPLING 7

// pin declaration
#define SDA_PIN  21
#define SCL_PIN  38

// variables for measured values
// SEN5x
float massConcentrationPm1p0;
float massConcentrationPm2p5;
float massConcentrationPm4p0;
float massConcentrationPm10p0;
float sen5xHumidity;
float sen5xTemperature;
float vocIndex;
float noxIndex;
// SCD4x
uint16_t co2 = 0;
float scd4xTemperature = 0.0f;
float scd4xHumidity = 0.0f;
// DPS368
float dps368Pressure = 0.0f;
float dps368Temperature = 0.0f;

// creating sensor instances
SensirionI2CScd4x scd4x;
SensirionI2CSen5x sen5x;
Dps3xx dps368 = Dps3xx();

// serial print a 16-bit unsigned integer in 4 digit HEX format by adding leading zeros
void printUint16Hex(uint16_t value) {
    Serial.print(value < 4096 ? "0" : "");
    Serial.print(value < 256 ? "0" : "");
    Serial.print(value < 16 ? "0" : "");
    Serial.print(value, HEX);
}

// serial print the SCD4x serial number using the printUint16Hex number formater function
void printSCD4xSerialNumber() {
    uint16_t serial0;
    uint16_t serial1;
    uint16_t serial2;

    uint16_t error;
    char errorMessage[256];

    error = scd4x.getSerialNumber(serial0, serial1, serial2);
    if (error) {
        Serial.print("Error trying to execute getSerialNumber(): ");
        errorToString(error, errorMessage, 256);
        Serial.println(errorMessage);
    } else {
        Serial.print("SCD40 Serial Number: 0x");
        printUint16Hex(serial0);
        printUint16Hex(serial1);
        printUint16Hex(serial2);
        Serial.println();
    }
    
}

// serial print the SEN5x serial number
void printSEN5xSerialNumber() {
    uint16_t error;
    char errorMessage[256];
    unsigned char serialNumber[32];
    uint8_t serialNumberSize = 32;

    error = sen5x.getSerialNumber(serialNumber, serialNumberSize);
    if (error) {
        Serial.print("Error trying to execute getSerialNumber(): ");
        errorToString(error, errorMessage, 256);
        Serial.println(errorMessage);
    } else {
        Serial.print(" Serial Number: ");
        Serial.println((char*)serialNumber);
    }
}

// serial print the SEN5x serial number, firmware and hardware version
void printSEN5xModuleVersions() {
    uint16_t error;
    char errorMessage[256];

    unsigned char productName[32];
    uint8_t productNameSize = 32;

    error = sen5x.getProductName(productName, productNameSize);

    if (error) {
        Serial.print("Error trying to execute getProductName(): ");
        errorToString(error, errorMessage, 256);
        Serial.println(errorMessage);
    } else {
        //Serial.print("ProductName:");
        Serial.print((char*)productName);
        printSEN5xSerialNumber();
    }

    bool firmwareDebug;
    uint8_t firmwareMajor;
    uint8_t firmwareMinor;
    uint8_t hardwareMajor;
    uint8_t hardwareMinor;
    uint8_t protocolMajor;
    uint8_t protocolMinor;

    error = sen5x.getVersion(firmwareMajor, firmwareMinor, firmwareDebug,
                             hardwareMajor, hardwareMinor, protocolMajor,
                             protocolMinor);
    if (error) {
        Serial.print("Error trying to execute getVersion(): ");
        errorToString(error, errorMessage, 256);
        Serial.println(errorMessage);
    } else {
        Serial.print("Firmware: ");
        Serial.print(firmwareMajor);
        Serial.print(".");
        Serial.print(firmwareMinor);
        Serial.print(", ");

        Serial.print("Hardware: ");
        Serial.print(hardwareMajor);
        Serial.print(".");
        Serial.println(hardwareMinor);
    }
}

void setup() {

    Serial.begin(BAUD_RATE);
    while (!Serial) {
        delay(100);
    }

    Wire.begin(SDA_PIN, SCL_PIN);

    scd4x.begin(Wire);  // default 0x62 I2C address
    sen5x.begin(Wire);  // default 0x69 I2C address
    dps368.begin(Wire); // default 0x76 I2C address

    delay(100);
    Serial.println("Booting...");

    // SCD4x Initialization
    // stop SCD4x potentially previously started measurement
    uint16_t scd4xError;
    char scd4xErrorMessage[256];
    scd4xError = scd4x.stopPeriodicMeasurement();
    if (scd4xError) {
        Serial.print("SCD4x Error trying to execute stopPeriodicMeasurement(): ");
        errorToString(scd4xError, scd4xErrorMessage, 256);
        Serial.println(scd4xErrorMessage);
    }

    // SEN5x Initialization
    // reset SEN5x 
    uint16_t sen5xError;
    char sen5xErrorMessage[256];
    sen5xError = sen5x.deviceReset();
    if (sen5xError) {
        Serial.print("SEN5x Error trying to execute deviceReset(): ");
        errorToString(sen5xError, sen5xErrorMessage, 256);
        Serial.println(sen5xErrorMessage);
    }

    // print sensor module information if I2C buffers are large enough
    #ifdef USE_PRODUCT_INFO
        printSCD4xSerialNumber();
        printSEN5xModuleVersions();
        // add ambient pressure sensor
    #endif

    #ifdef SEN5X_TEMP_OFFSET
        // set temperature offset for SEN5x
        sen5xError = sen5x.setTemperatureOffsetSimple(SEN5X_TEMP_OFFSET);
        if (sen5xError) {
            Serial.print("SEN5x Error trying to execute setTemperatureOffsetSimple(): ");
            errorToString(sen5xError, sen5xErrorMessage, 256);
            Serial.println(sen5xErrorMessage);
        } else {
            Serial.print("SEN5x Temperature Offset set to ");
            Serial.print(SEN5X_TEMP_OFFSET);
            Serial.println(" °C (SEN54/SEN55 only)");
        }
    #endif
    
    // start SCD4x Measurement
    scd4xError = scd4x.startPeriodicMeasurement();
    if (scd4xError) {
        Serial.print("SCD4x Error trying to execute startPeriodicMeasurement(): ");
        errorToString(scd4xError, scd4xErrorMessage, 256);
        Serial.println(scd4xErrorMessage);
    }

    // SEN5x start Measurement
    sen5xError = sen5x.startMeasurement();
    if (sen5xError) {
        Serial.print("SEN5x Error trying to execute startMeasurement(): ");
        errorToString(sen5xError, sen5xErrorMessage, 256);
        Serial.println(sen5xErrorMessage);
    }

    // add more sensor initializations here

    Serial.println("Waiting for first measurement... (5 sec)");
}
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

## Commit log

2024-10-24 started schematic work
    [100008_hw-vern-aqm.kicad_pcb, 100008_hw-vern-aqm.kicad_sch, Block Diagram.kicad_sch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]
2024-10-24 end of day work
    [100008_hw-vern-aqm.kicad_sch, Project Architecture.kicad_sch, connectors-and-power.kicad_sch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]
2024-10-25 mid day progress
    [100008_hw-vern-aqm.kicad_sch, connectors-and-power.kicad_sch, sensors.kicad_sch]
2024-10-26 added block diagram
    [connectors-and-power.kicad_sch, sensors.kicad_sch]
2024-10-26 renamed folders
    [100008_hw-vern-aqm.kicad_pcb, 100008_hw-vern-aqm.kicad_sch, Block Diagram.kicad_sch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]
2024-10-29 schematic work
    [connectors-and-power.kicad_sch, mcu-esp32.kicad_sch, sensors.kicad_sch]
2024-11-03 schematic and pcb work
    [100008_hw-vern-aqm.kicad_pcb, connectors-and-power.kicad_sch, mcu-esp32.kicad_sch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]
2024-11-04 schematic and pcb layout
    [100008_hw-vern-aqm.kicad_pcb, connectors-and-power.kicad_sch, mcu-esp32.kicad_sch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]
2024-11-05 schematic and pcb general layout
    [100008_hw-vern-aqm.kicad_pcb, connectors-and-power.kicad_sch]
2024-11-06 schematic, pcb layout, added mouser shoping cart
    [100008_hw-vern-aqm.kicad_pcb, connectors-and-power.kicad_sch, mcu-esp32.kicad_sch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]
2024-11-06 pcb routing
    [100008_hw-vern-aqm.kicad_pcb, SM04B-SRSS-TB.STEP, mcu-esp32.kicad_sch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]
2024-11-07 pcb layout
    [100008_hw-vern-aqm.kicad_pcb, connectors-and-power.kicad_sch, mcu-esp32.kicad_sch]
2024-11-07 PCB routing and DRC fixes
    [100008_hw-vern-aqm.kicad_pcb, 100008_hw-vern-aqm.kicad_sch, Block Diagram.kicad_sch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]
2024-11-08 fixing DRC issues
    [100008_hw-vern-aqm.kicad_pcb, connectors-and-power.kicad_sch, mcu-esp32.kicad_sch]
2024-11-11 schematic release, pcb release
    [100008_hw-vern-aqm-B_Mask.gbs, 100008_hw-vern-aqm-B_Silkscreen.gbo, 100008_hw-vern-aqm-Edge_Cuts.gm1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]
2024-11-12 added block diagram on eng
    [100008_hw-vern-aqm-drl_map.dxf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]
2024-12-06 added display functionality, wifi is not working yet
    [main.cpp]
2024-12-11 update case-design photo, removed old block diagram files
2024-12-12 added measurement units to display and live sensor readings
2024-12-13 added work in progress data logger script
    [sensor_data.csv]
2024-12-20 added multiple cpp files, testing wifi, fixed user_setup resetting issue
    [main.cpp, sensor-test.cpp, wifi-test.cpp]
2025-01-06 fixed the value color display, moved the functions to lcd_functions
    [main.cpp]
2025-01-28 fixed getPressureColor()
    [sensor_data.csv]
